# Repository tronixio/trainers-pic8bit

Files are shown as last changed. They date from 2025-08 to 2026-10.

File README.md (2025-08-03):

# PIC 8-Bit Trainers Boards.

## Schematics.

- [**Nano** Trainer.](https://github.com/tronixio/trainers-pic8bit/blob/main/Kicad/nano/extras/schematic.pdf)
- [TODO - Micro Trainer.](https://github.com/tronixio/trainers-pic8bit/blob/main/Kicad/micro/extras/schematic.pdf)
- [**Mini** Trainer.](https://github.com/tronixio/trainers-pic8bit/blob/main/Kicad/mini/extras/schematic.pdf)
- [**PIC 8-Bit** Trainer.](https://github.com/tronixio/trainers-pic8bit/blob/main/Kicad/trainer/extras/schematic.pdf)

## Firmwares.

- [PIC 8-Bit NANO Trainer.](https://github.com/tronixio/trainers-pic8bit/tree/main/Firmwares#pic8-bit-nano-trainer)
- [PIC 8-Bit MINI Trainer.](https://github.com/tronixio/trainers-pic8bit/tree/main/Firmwares#pic8-bit-mini-trainer)
- [PIC 8-Bit Trainer.](https://github.com/tronixio/trainers-pic8bit/tree/main/Firmwares#pic8-bit-trainer)

## Hats & Modules.

- [Trainer Hats](https://github.com/tronixio/modules)
- [Trainer Modules (GPIO/UART/I2C/SPI)](https://github.com/tronixio/modules)

## NANO Trainer Top.

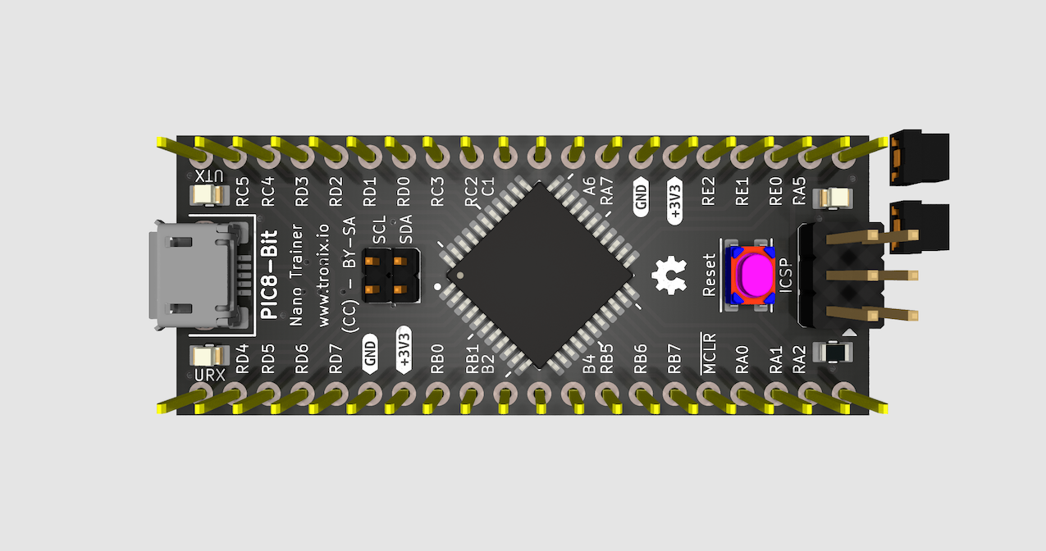
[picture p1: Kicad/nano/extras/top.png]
Nano Trainer Top.


## NANO Trainer Bottom.

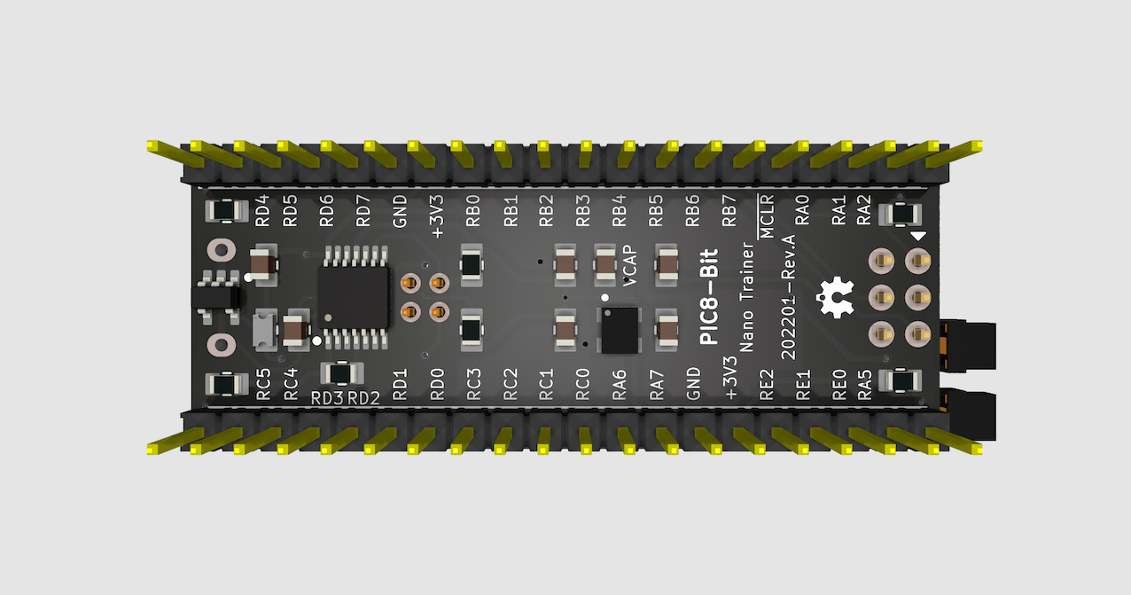
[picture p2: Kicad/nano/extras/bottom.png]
Nano Trainer Bottom.


## MINI Trainer Top.

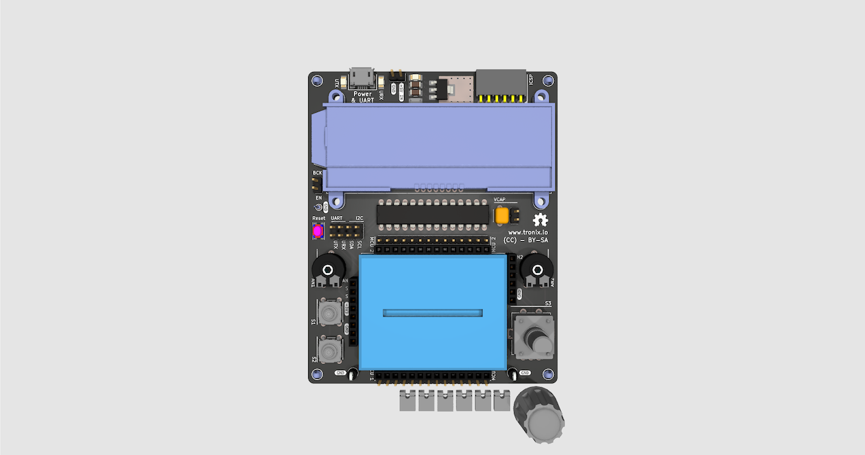
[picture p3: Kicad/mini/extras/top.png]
Mini Trainer Top.


## MINI Trainer Bottom.

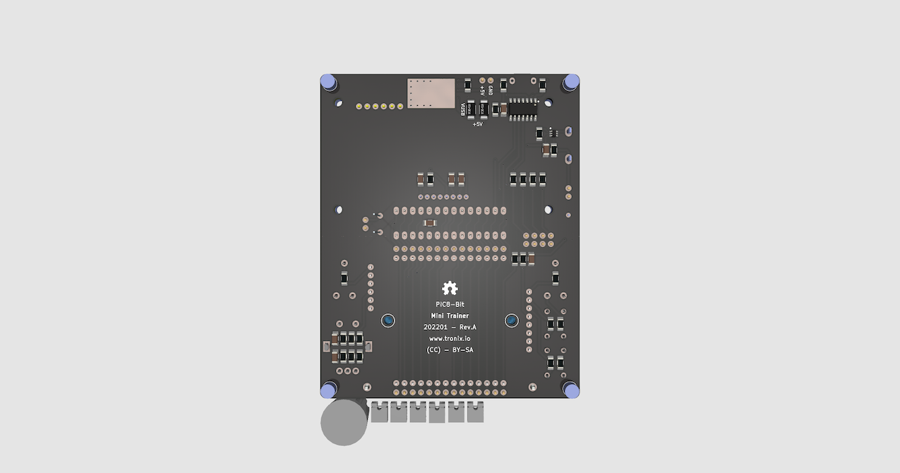
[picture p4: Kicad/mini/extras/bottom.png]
Mini Trainer Bottom.


## PIC 8-Bit Trainer Top.

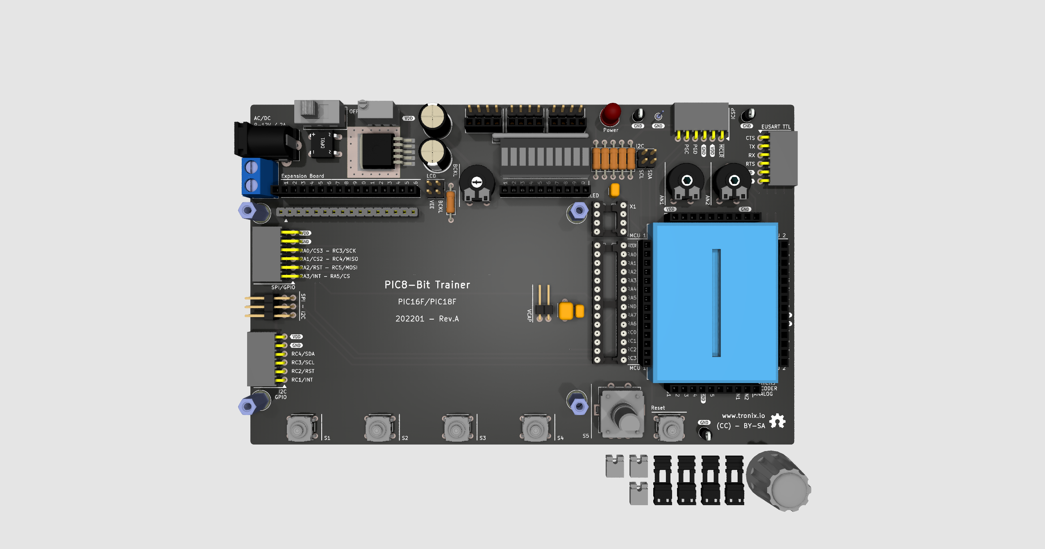
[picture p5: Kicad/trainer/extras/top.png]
PIC 8-Bit Trainer Top.


## PIC 8-Bit Trainer Bottom.

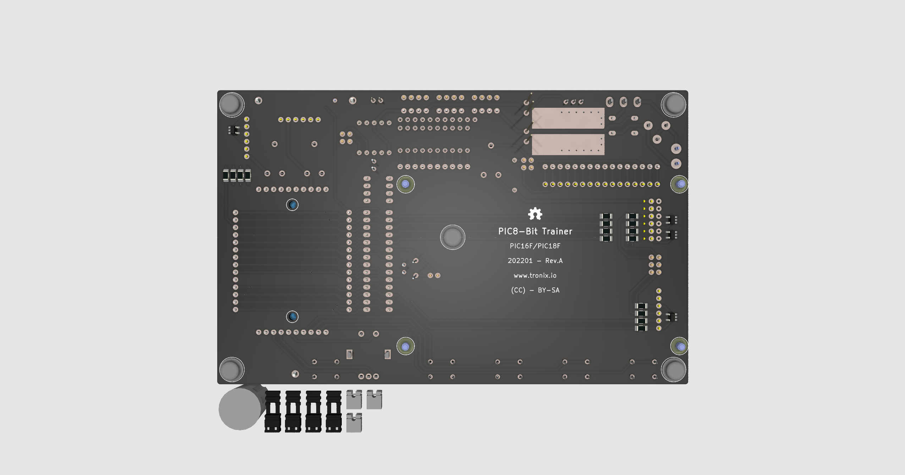
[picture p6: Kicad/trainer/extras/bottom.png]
PIC 8-Bit Trainer Bottom.


## Notes.

- DRAFT : Prototype OK, last check schematic, PCB & code can be modify.
- TODO : Work in progress, prototype was not good, hardware, PCB and code can be rework.

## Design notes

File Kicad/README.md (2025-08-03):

# Trainers Boards PIC 8-Bit.

- [Trainers Boards PIC 8-Bit.](https://github.com/tronixio/trainers-pic8bit)

## Notes.

- TODO : Work in progress, prototype was not good, hardware, PCB and code can be rework.
- DRAFT : Prototype OK, last check schematic, PCB & code can be modify.

## DISCLAIMER.

THIS CODE IS PROVIDED WITHOUT ANY WARRANTY OR GUARANTEES.
USERS MAY USE THIS CODE FOR DEVELOPMENT AND EXAMPLE PURPOSES ONLY.
AUTHORS ARE NOT RESPONSIBLE FOR ANY ERRORS, OMISSIONS, OR DAMAGES THAT COULD
RESULT FROM USING THIS FIRMWARE IN WHOLE OR IN PART.

---

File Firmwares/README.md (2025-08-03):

# FIRMWARES - PIC 8-Bit Trainers Boards.

## PIC8-Bit Nano Trainer.

## PIC8-Bit Mini Trainer.

- [TODO - PIC16f1778 PICAS Eusart](./pic16f17xx/pic16f1778-mini-picas-eusart.s)
- [TODO - PIC16f1778 PICAS LCD](./pic16f17xx/pic16f1778-mini-picas-lcd.s)
- [TODO - PIC16f1778 XC8 EUSART](./pic16f17xx/pic16f1778-mini-xc8-eusart.c)
- [TODO - PIC16f1778 XC8 LCD](./pic16f17xx/pic16f1778-mini-xc8-lcd.c)

## PIC8-Bit Trainer.

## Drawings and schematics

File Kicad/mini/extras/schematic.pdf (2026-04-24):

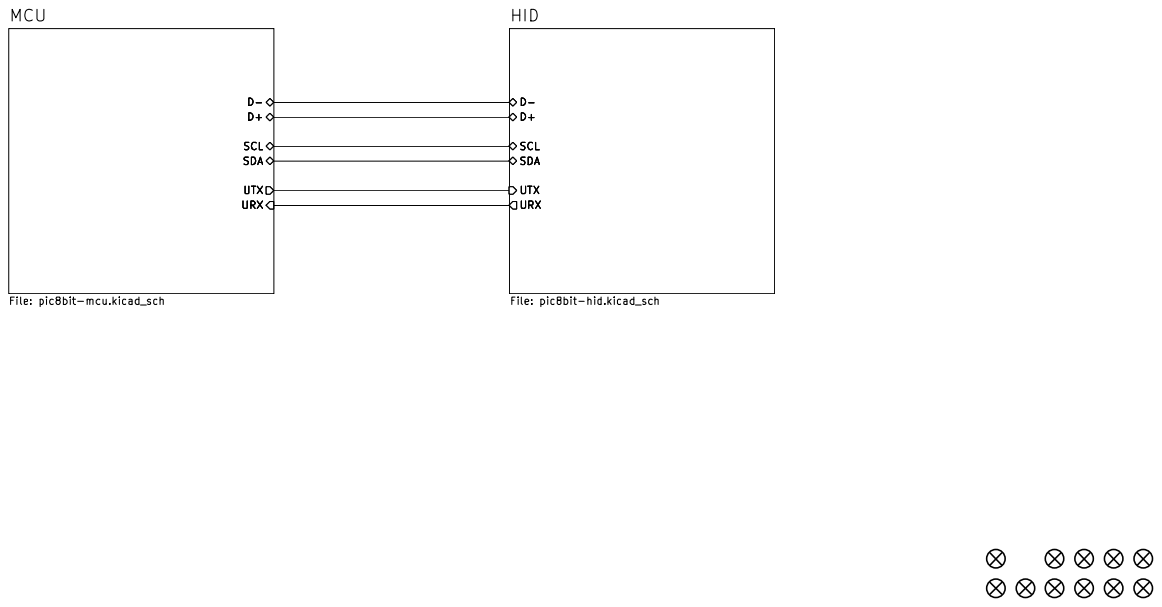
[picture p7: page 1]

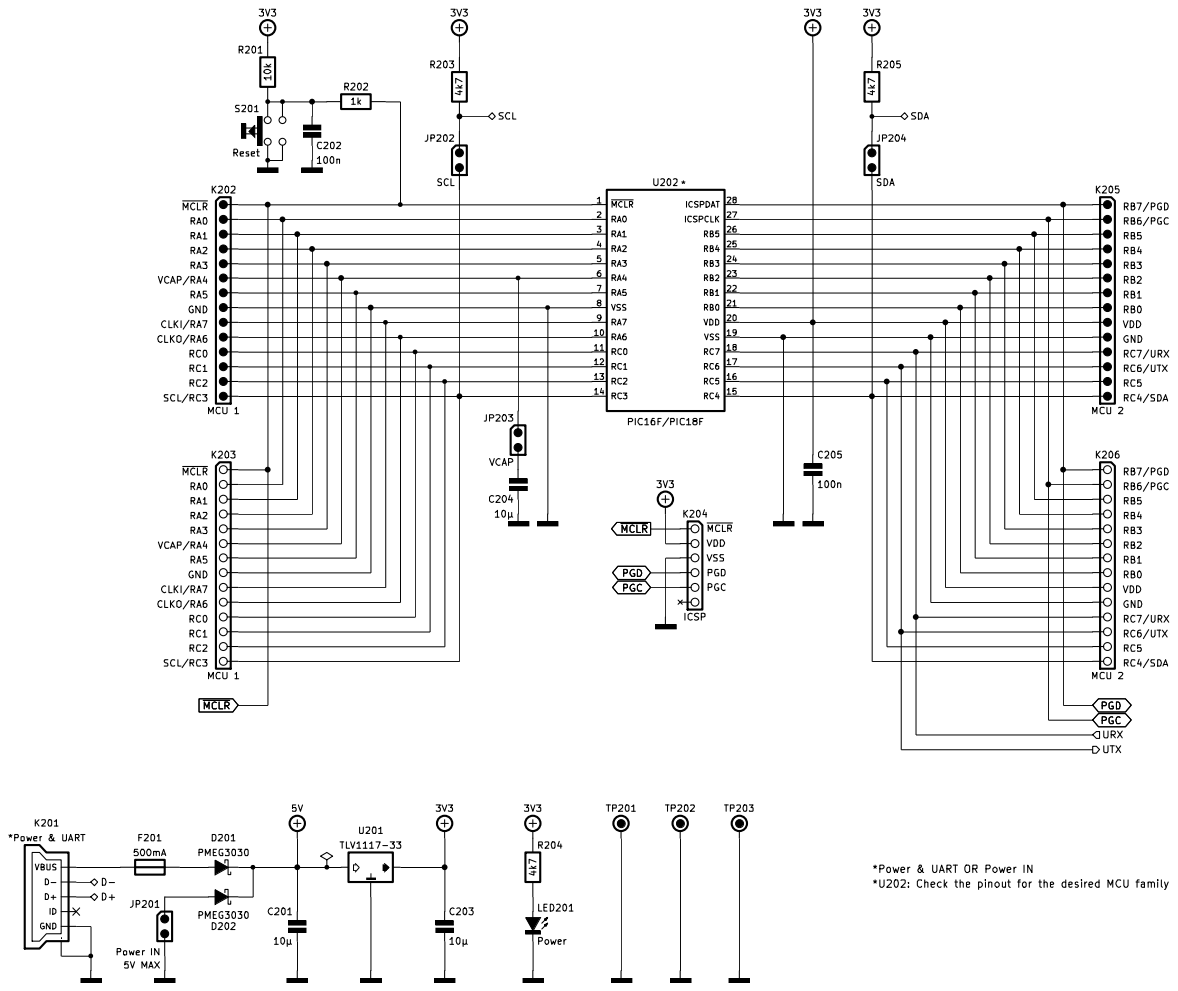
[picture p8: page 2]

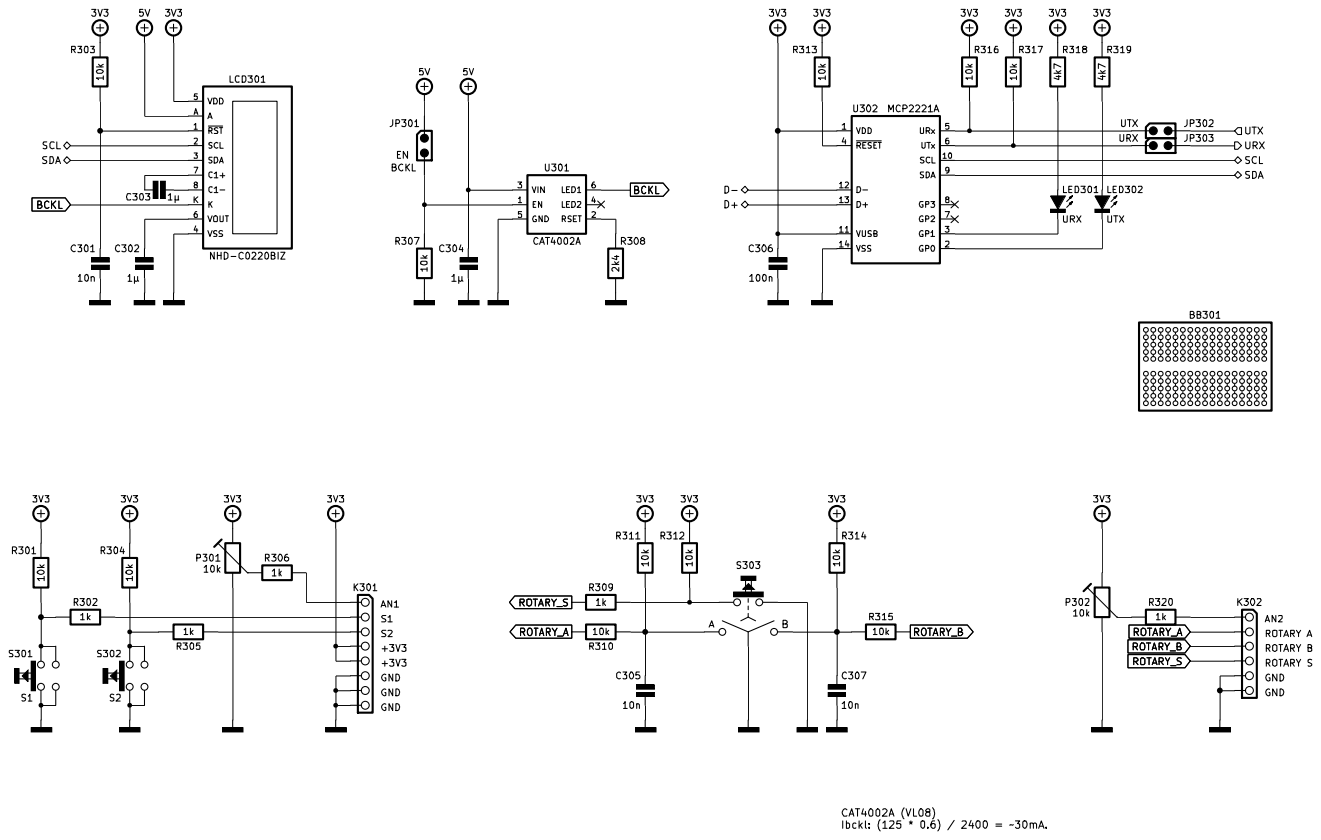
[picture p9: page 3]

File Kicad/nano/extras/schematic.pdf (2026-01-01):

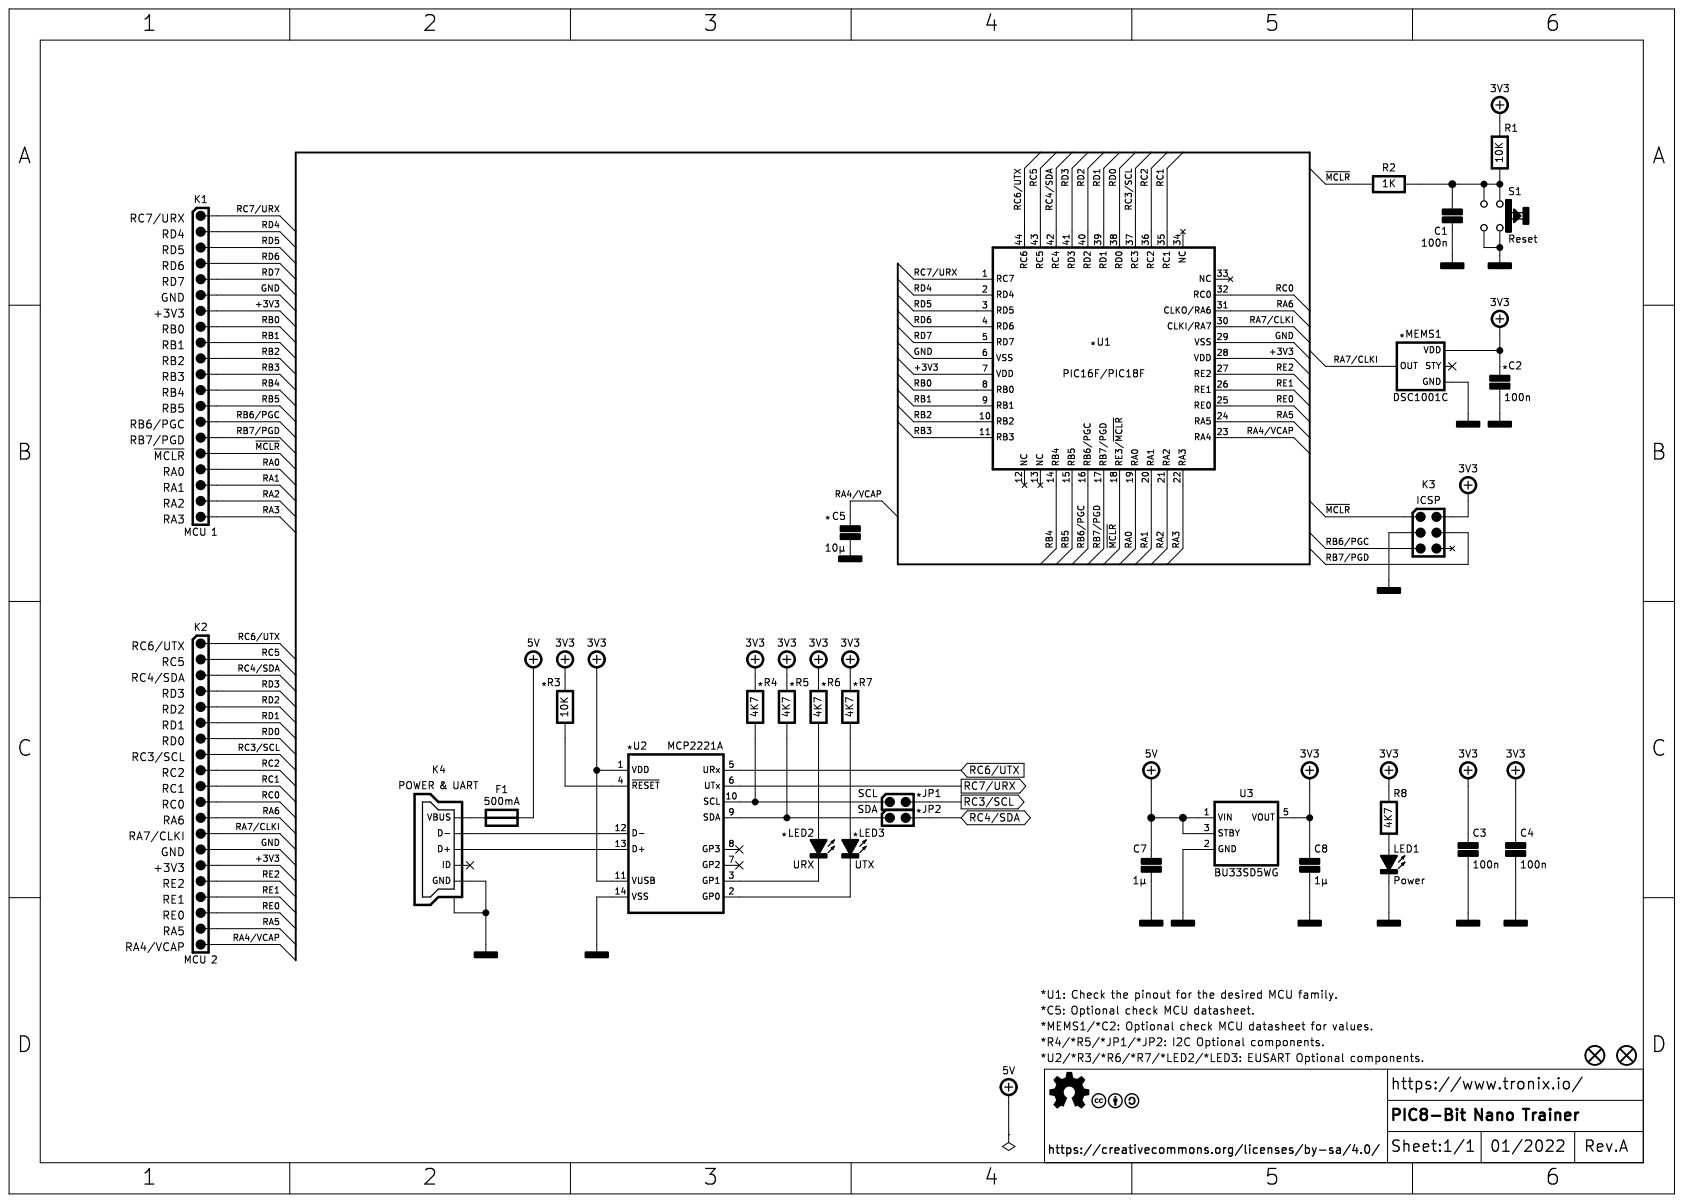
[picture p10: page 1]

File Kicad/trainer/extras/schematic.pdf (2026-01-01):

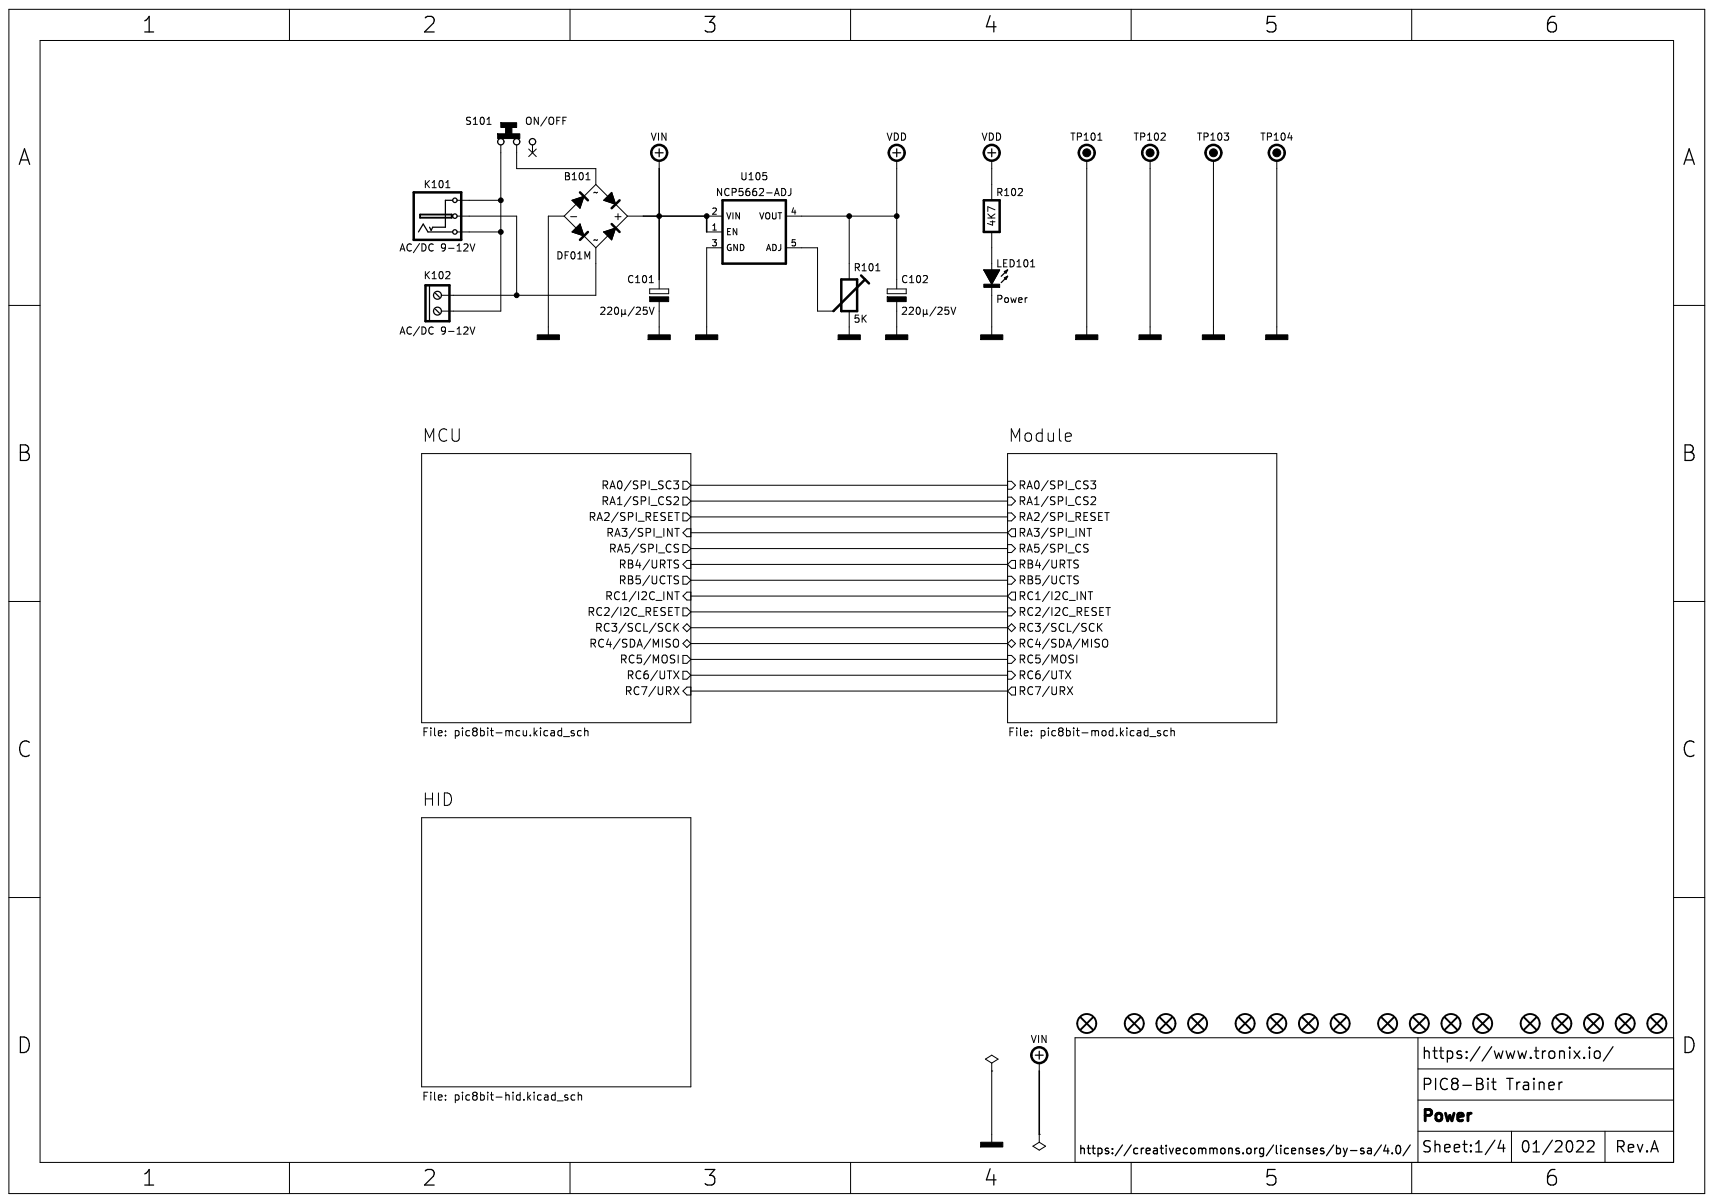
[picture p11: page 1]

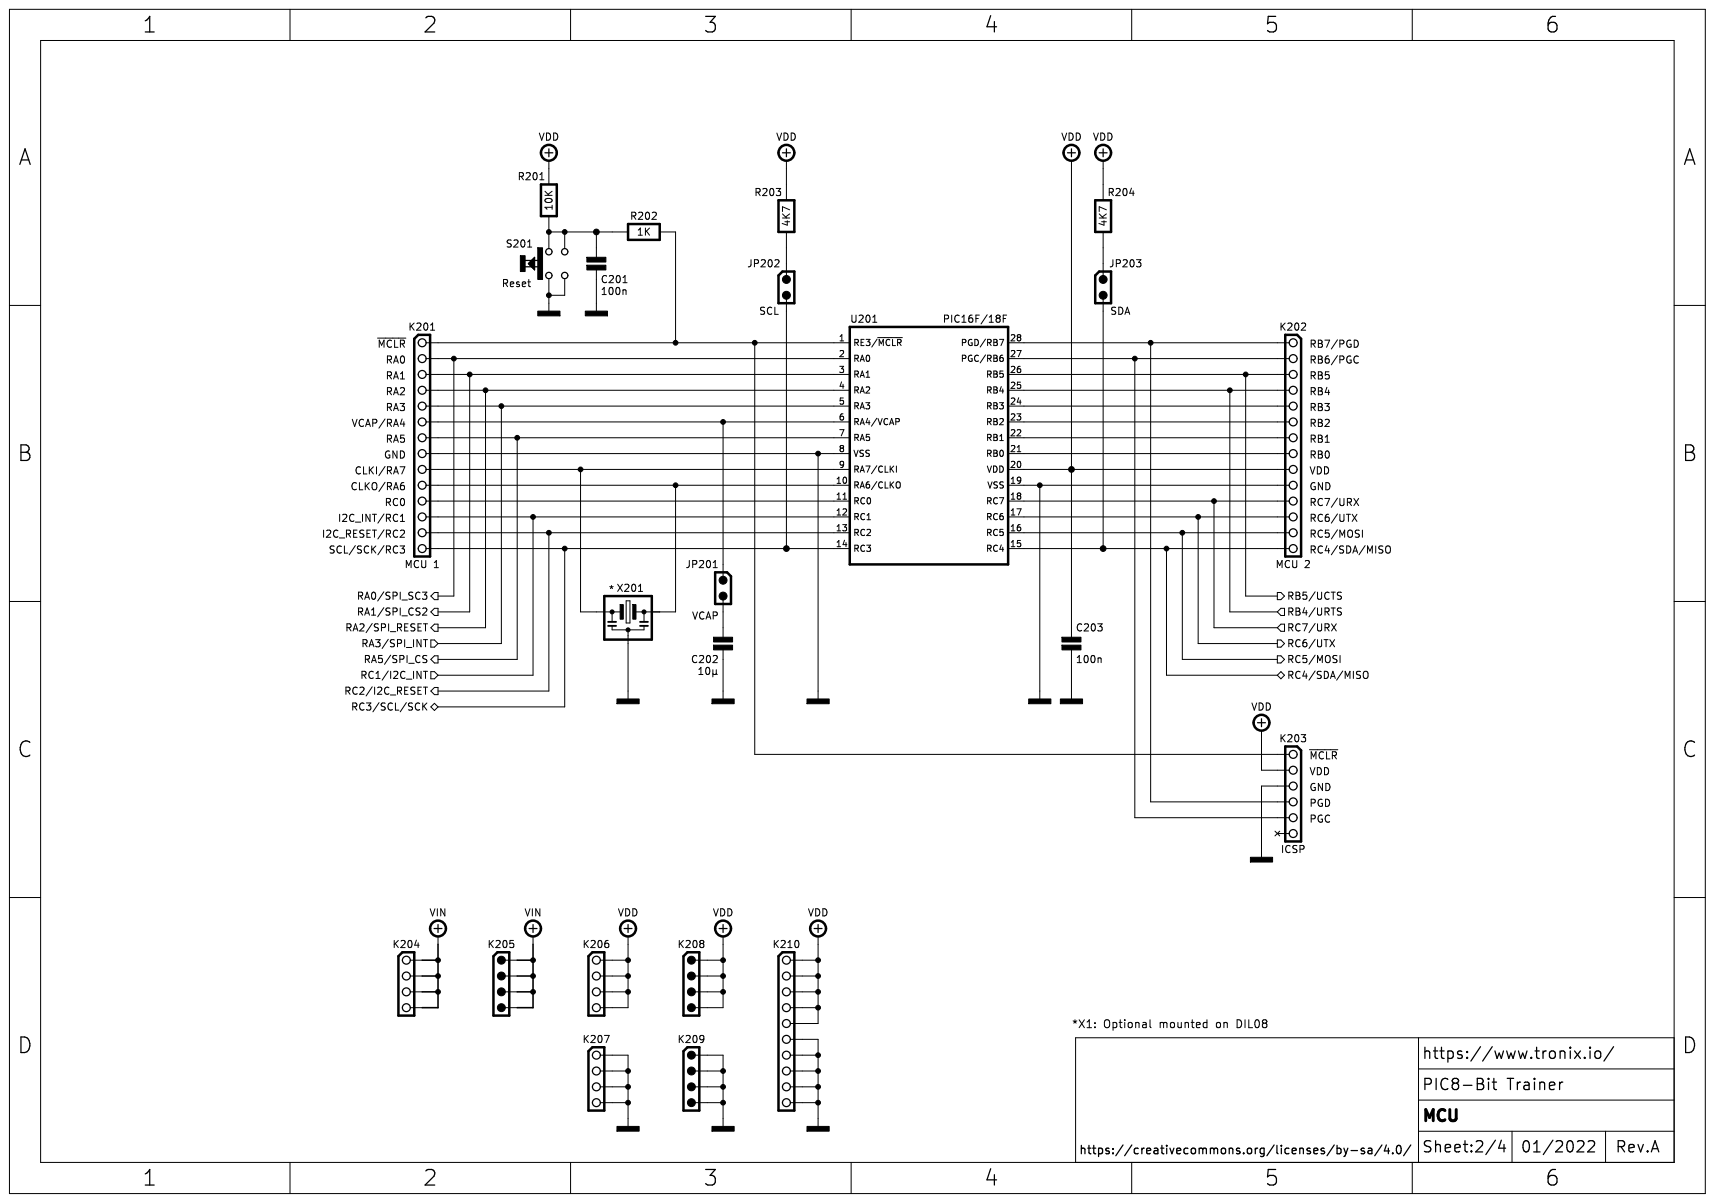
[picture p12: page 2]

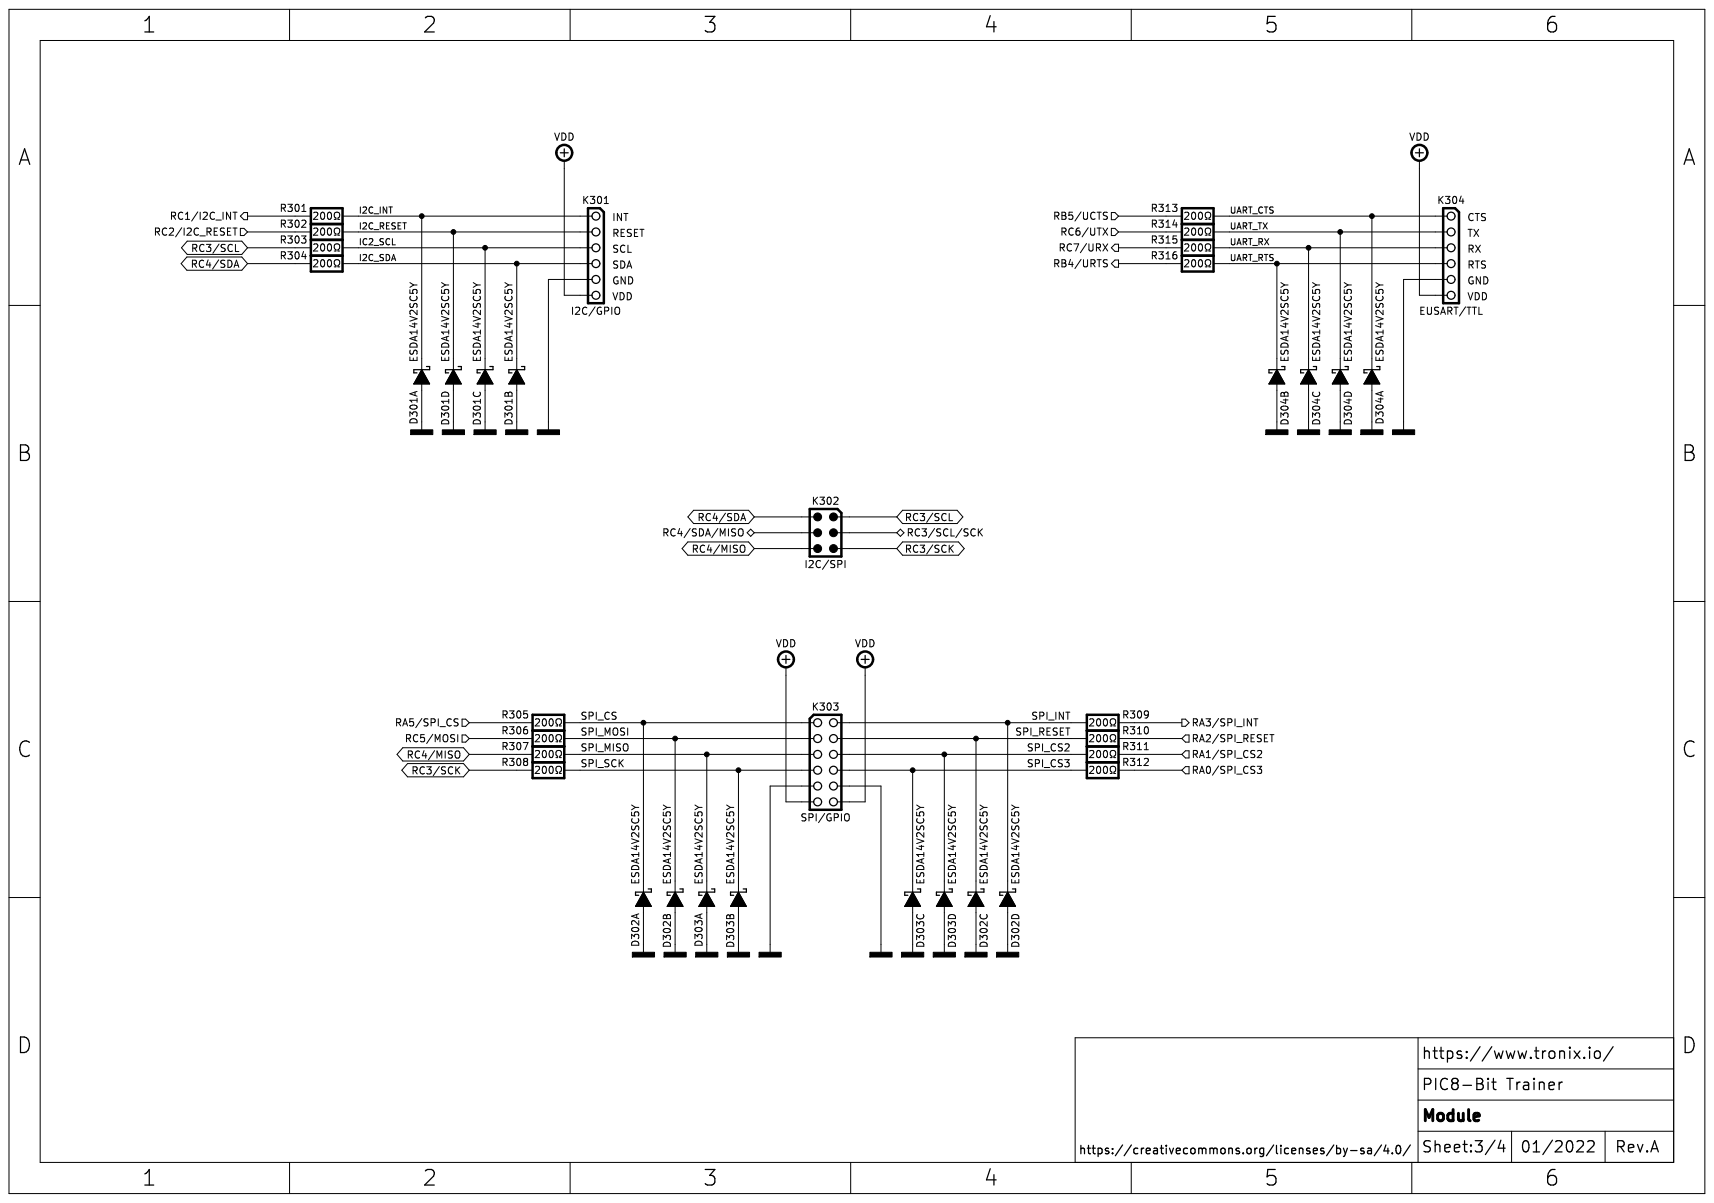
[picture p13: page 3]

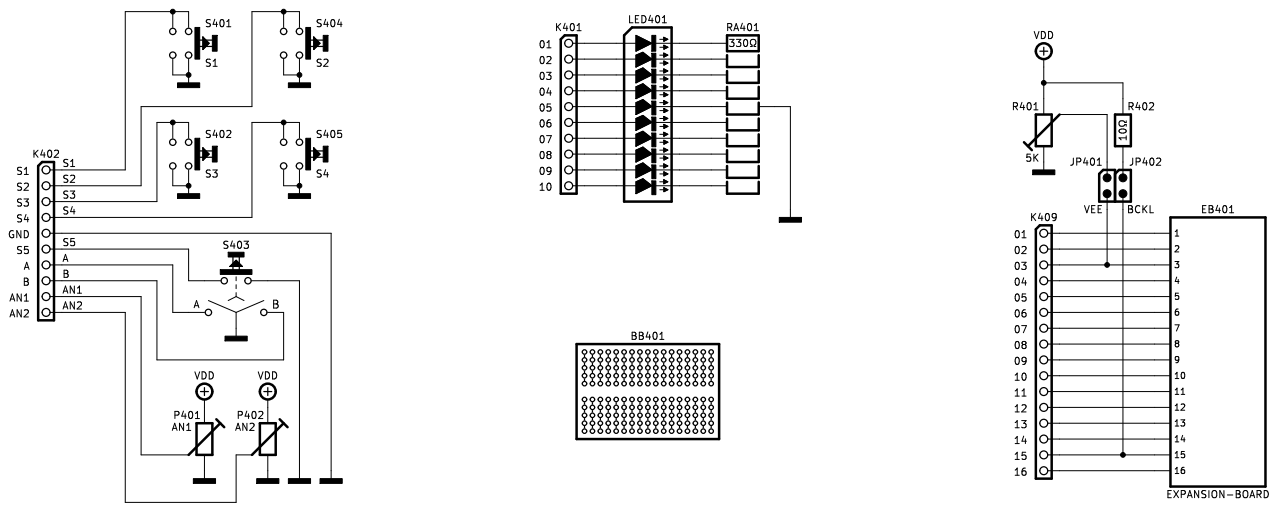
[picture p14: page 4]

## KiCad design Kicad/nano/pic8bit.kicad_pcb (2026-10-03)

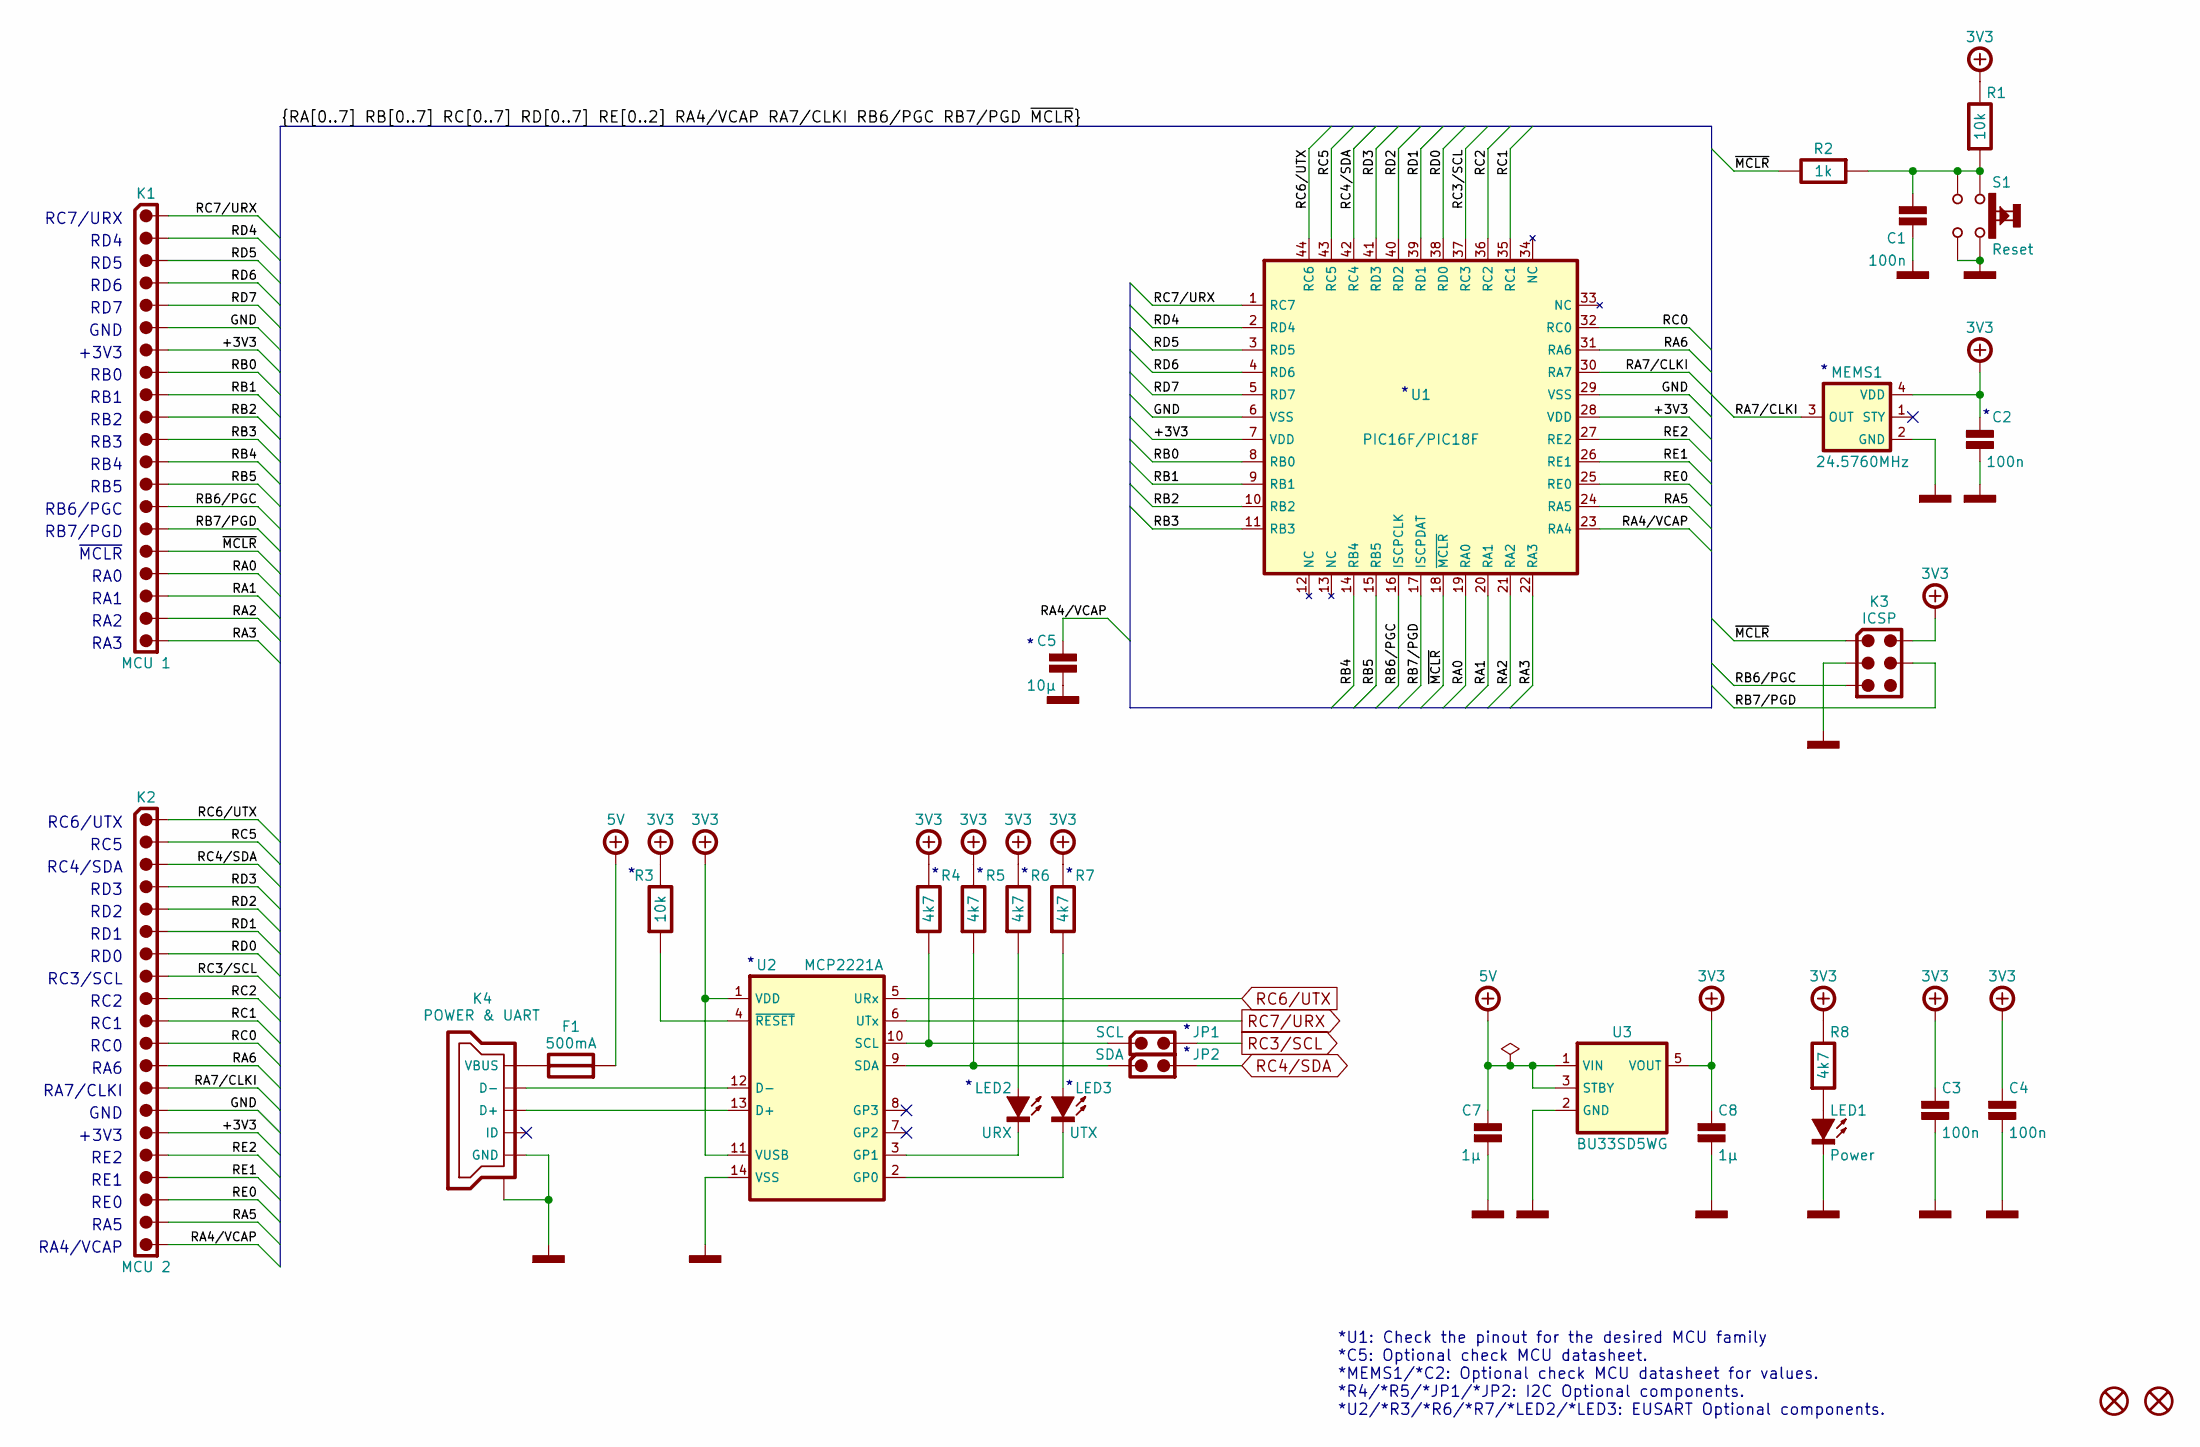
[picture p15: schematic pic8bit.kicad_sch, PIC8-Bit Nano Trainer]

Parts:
C1, C2, C3, C4: 100n; CAPACITOR-SMD-0805; Voltage 50V; Tolerance 5%; Mouser 80-C0805C104J5
C5: 10µ; CAPACITOR-SMD-0805; Voltage 25V; Tolerance 10%; Mouser 81-GRM21BZ71E106
C7, C8: 1µ; CAPACITOR-SMD-0805; Voltage 50V; Tolerance 10%; Mouser 187-CL21B105KBFNNNE
F1: 500mA; FUSE-SMD-0805; Mouser 652-MF-PSMF050X-2
H1, H2: HARWIN-JUMPER-0200-03MM-BLACK; HARWIN-M22-190-19X; Mouser 855-M22-19000
JP1: SCL; HARWIN-M22-25102xx; Mouser 855-M22-25102
JP2: SDA; HARWIN-M22-25102xx; Mouser 855-M22-25102
K1: MCU 1; SAMTEC-TSW-120-22-T-S; Mouser 200-TSW12022TS
K2: MCU 2; SAMTEC-TSW-120-22-T-S; Mouser 200-TSW12022TS
K3: ICSP; HARWIN-M20-998034x; Mouser 855-M20-998034
K4: POWER & UART; USB-TYPE-B-MICRO-TH; Mouser 649-10118193-0001LF
LED1: Power; LED-SMD-0805; Mouser 604-APT2012LVBCD
LED2: URX; LED-SMD-0805; Mouser 604-APT2012LVBCD
LED3: UTX; LED-SMD-0805; Mouser 604-APT2012LVBCD
MEMS1: 24.5760MHz; CDFN-3225; Mouser 998-1001CI2-024.5760
R1, R3: 10k; RESISTOR-SMD-0805; Tolerance 5%; Mouser 660-RK73B2ATTDD103J
R2: 1k; RESISTOR-SMD-0805; Tolerance 5%; Mouser 660-RK73B2ATTDD102J
R4, R5, R6, R7, R8: 4k7; RESISTOR-SMD-0805; Tolerance 5%; Mouser 660-RK73B2ATTDD472J
S1: Reset; ALPS-SKRPAC; Mouser 688-SKRPACE010
U1: PIC16F/PIC18F; TQFP-44; Mouser 579-PIC16F1779-I/PT
U2: MCP2221A; TSSOP-14; Mouser 579-MCP2221A-I/ST
U3: BU33SD5WG; SOT-23-5; Mouser 755-BU33SD5WG-TR

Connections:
+3V3: C2.1, C3.1, C4.1, C8.1, K1.7, K2.15, K3.2 (VCC), MEMS1.4 (VDD), R1.1, R3.1, R4.1, R5.1, R6.1, R7.1, R8.1, U1.7 (VDD), U1.28 (VDD), U2.1 (VDD), U2.11 (VUSB), U3.5 (VOUT)
/RA0: K1.17, U1.19 (RA0)
/RA1: K1.18, U1.20 (RA1)
/RA2: K1.19, U1.21 (RA2)
/RA3: K1.20, U1.22 (RA3)
/RA4/VCAP: C5.1, K2.20, U1.23 (RA4)
/RA5: K2.19, U1.24 (RA5)
/RA6: K2.12, U1.31 (RA6)
/RA7/CLKI: K2.13, MEMS1.3 (OUT), U1.30 (RA7)
/RB0: K1.8, U1.8 (RB0)
/RB1: K1.9, U1.9 (RB1)
/RB2: K1.10, U1.10 (RB2)
/RB3: K1.11, U1.11 (RB3)
/RB4: K1.12, U1.14 (RB4)
/RB5: K1.13, U1.15 (RB5)
/RB6/PGC: K1.14, K3.5 (ICSPCLK), U1.16 (ISCPCLK)
/RB7/PGD: K1.15, K3.4 (ICSPDAT), U1.17 (ISCPDAT)
/RC0: K2.11, U1.32 (RC0)
/RC1: K2.10, U1.35 (RC1)
/RC2: K2.9, U1.36 (RC2)
/RC5: K2.2, U1.43 (RC5)
/RD0: K2.7, U1.38 (RD0)
/RD1: K2.6, U1.39 (RD1)
/RD2: K2.5, U1.40 (RD2)
/RD3: K2.4, U1.41 (RD3)
/RD4: K1.2, U1.2 (RD4)
/RD5: K1.3, U1.3 (RD5)
/RD6: K1.4, U1.4 (RD6)
/RD7: K1.5, U1.5 (RD7)
/RE0: K2.18, U1.25 (RE0)
/RE1: K2.17, U1.26 (RE1)
/RE2: K2.16, U1.27 (RE2)
/~MCLR: K1.16, K3.1 (~MCLR), R2.1, U1.18 (~MCLR)
GND: C1.2, C2.2, C3.2, C4.2, C5.2, C7.2, C8.2, K1.6, K2.14, K3.3 (GND), K4.5 (GND), K4.SH (SHIELD), LED1.1 (C), MEMS1.2 (GND), S1.3, S1.4, U1.6 (VSS), U1.29 (VSS), U2.14 (VSS), U3.2 (GND)
unnamed: C1.1, R1.2, R2.2, S1.1, S1.2
unnamed: K4.3 (D+), U2.13 (D+)
unnamed: K4.2 (D-), U2.12 (D-)
unnamed: F1.1, K4.1 (VBUS)
unnamed: LED1.2 (A), R8.2
unnamed: LED2.2 (A), R6.2
unnamed: LED2.1 (C), U2.3 (GP1)
unnamed: LED3.2 (A), R7.2
unnamed: LED3.1 (C), U2.2 (GP0)
unnamed: JP1.1, R4.2, U2.10 (SCL)
unnamed: JP2.1, R5.2, U2.9 (SDA)
unnamed: R3.2, U2.4 (~RESET)
POWER-+5V: C7.1, F1.2, U3.1 (VIN), U3.3 (STBY)
RC3/SCL: JP1.2, K2.8, U1.37 (RC3)
RC4/SDA: JP2.2, K2.3, U1.42 (RC4)
RC6/UTX: K2.1, U1.44 (RC6), U2.5 (URx)
RC7/URX: K1.1, U1.1 (RC7), U2.6 (UTx)

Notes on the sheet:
RD7
RA7/CLKI
RB0
RD5
RC6/UTX
GND
RB4
RA4/VCAP
RB1
RE0
RC3/SCL
~{MCLR}
RB2
+3V3
RE1
RB5
RA6
RD1
RD3
RD6
RB3
RA3
*U1: Check the pinout for the desired MCU family *C5: Optional check MCU datasheet. *MEMS1/*C2: Optional check MCU datasheet for values. *R4/*R5/*JP1/*JP2: I2C Optional components. *U2/*R3/*R6/*R7/*LED2/*LED3: EUSART Optional components.
RE2
RA1
RB7/PGD
RA2
RC5
RC0
RC4/SDA
RA0
RA5
RB6/PGC
RD2
RD0
RC2
RC7/URX
RC1
RD4

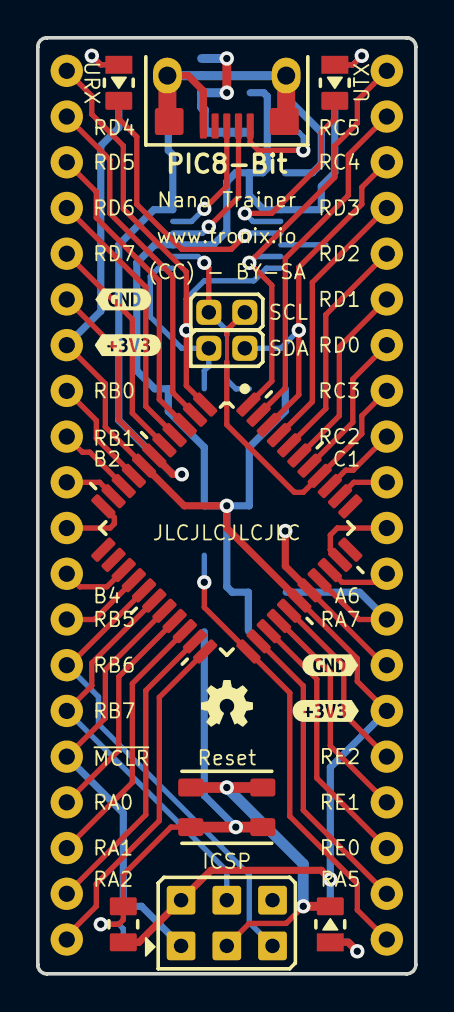
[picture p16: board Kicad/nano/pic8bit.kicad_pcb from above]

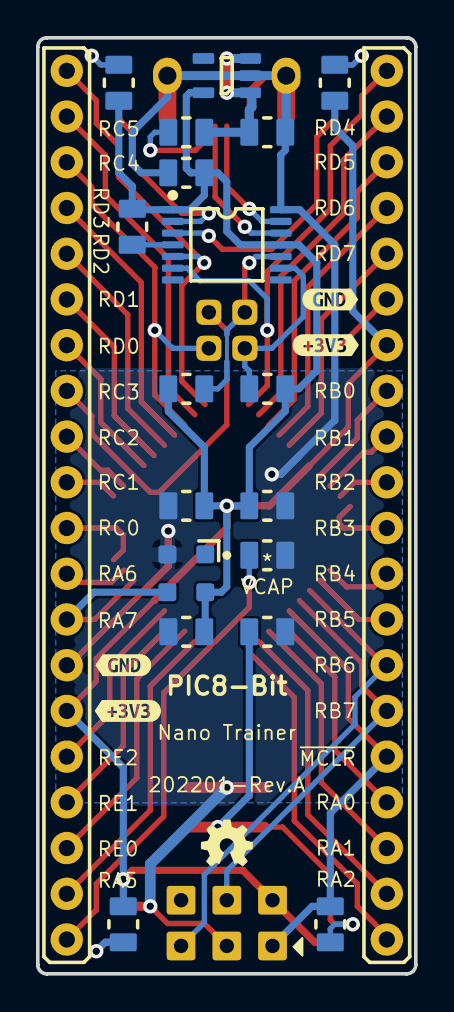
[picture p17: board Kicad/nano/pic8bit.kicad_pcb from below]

Board: 2 copper layers, 21.0 x 52.0 mm, 42 parts (25 on the bottom side), 51 nets.

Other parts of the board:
GB: LOGO; OSHW-3MM
GT: LOGO; OSHW-3MM
kibuzzard-65F5BE0B: G***; kibuzzard-65F5BE0B
kibuzzard-65F5BE2C: G***; kibuzzard-65F5BE2C
kibuzzard-65F5BE3D: G***; kibuzzard-65F5BE3D
kibuzzard-65F5BE5D: G***; kibuzzard-65F5BE5D
kibuzzard-65F5BE6D: G***; kibuzzard-65F5BE6D
kibuzzard-65F5BE7D: G***; kibuzzard-65F5BE7D
kibuzzard-65F5BE8C: G***; kibuzzard-65F5BE8C
kibuzzard-65F5BE49: G***; kibuzzard-65F5BE49

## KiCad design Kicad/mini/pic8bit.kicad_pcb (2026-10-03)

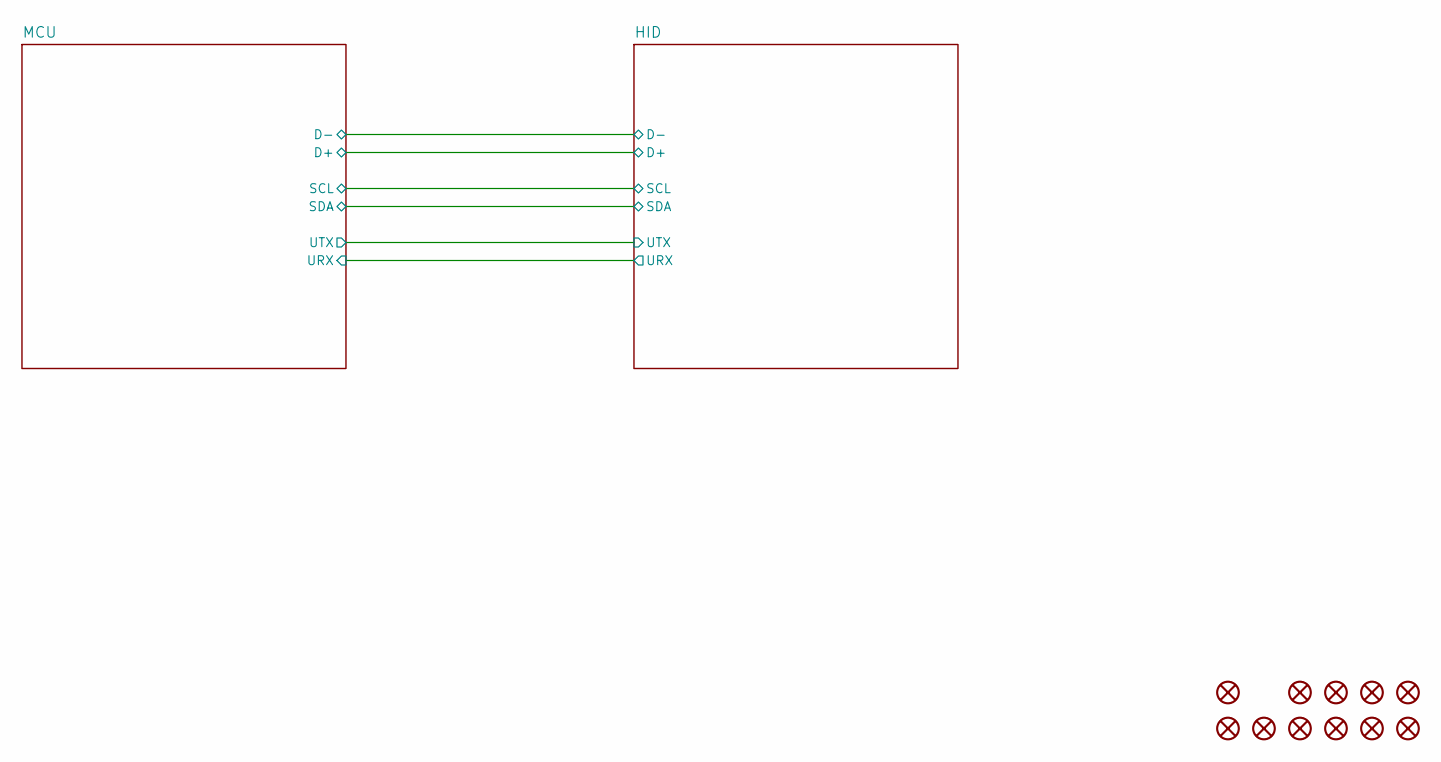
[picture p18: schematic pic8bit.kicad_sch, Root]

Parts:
H101, H102, H103, H104: KEYSTONE-9055; Mouser 534-9055
JP101, JP102, JP103, JP104, JP105, JP106: HARWIN-JUMPER-0254-06MM-BLACK; HARWIN-M20-7580-7583; Mouser 855-M7582
K101: PE-450-4X6X-BLACK; PE-450-4X6X; Mouser 450-476

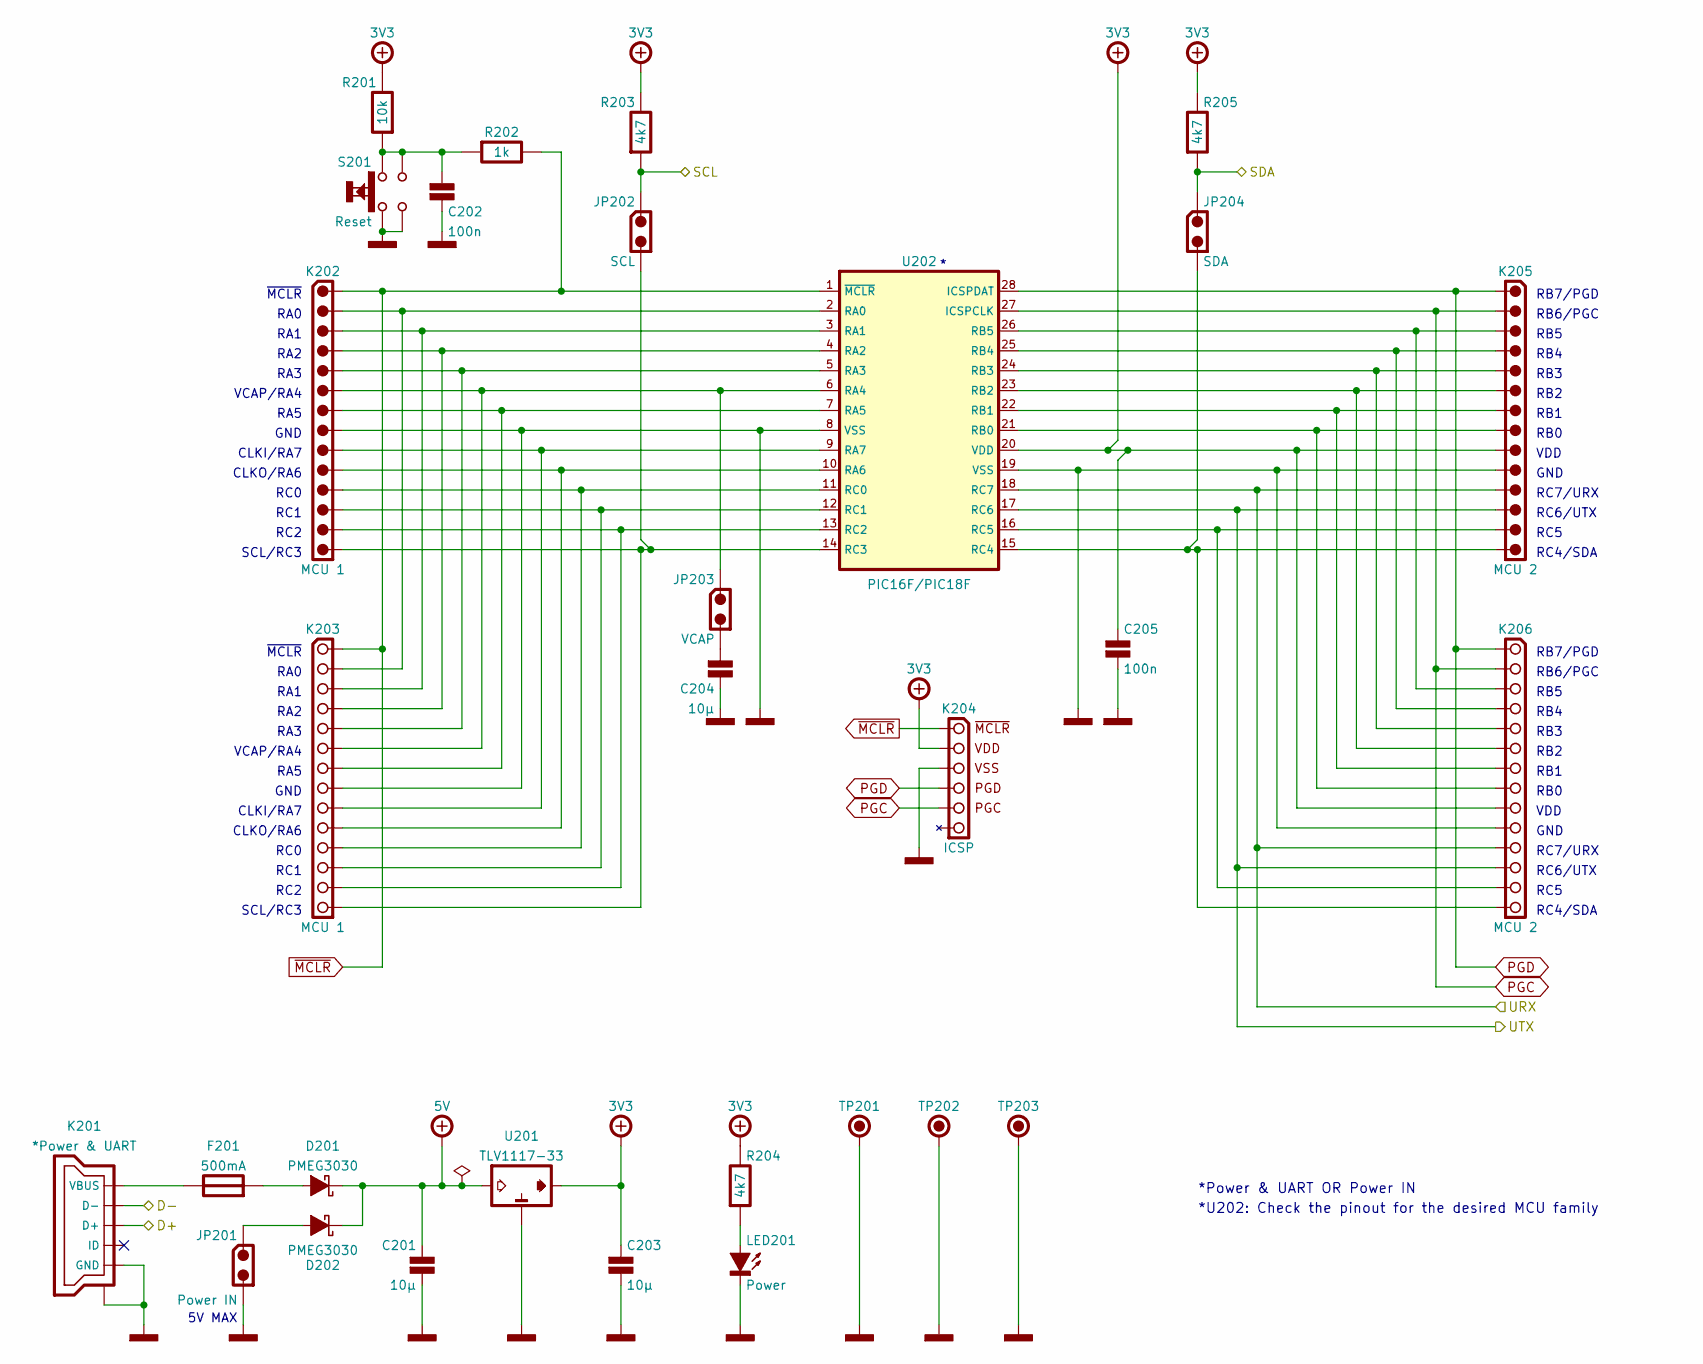
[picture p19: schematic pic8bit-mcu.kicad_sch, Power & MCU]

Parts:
C201, C203, C204: 10µ; CAPACITOR-SMD-1206; Tolerance 5%; Voltage 25V; Mouser 80-C1206C106J3R
C202, C205: 100n; CAPACITOR-SMD-1206; Voltage 50V; Tolerance 5%; Mouser 80-C1206C104J5R
D201, D202: PMEG3030; SOD-128; Part Marking A5; Mouser 771-PMEG3030EP115
F201: 500mA; FUSE-SMD-1206; Mouser 652-MF-NSMF050-2
JP201: Power IN; HARWIN-M20-999024x; Mouser 855-M20-999024
JP202: SCL; HARWIN-M20-999024x; Mouser 855-M20-999024
JP203: VCAP; HARWIN-M20-999024x; Mouser 855-M20-999024
JP204: SDA; HARWIN-M20-999024x; Mouser 855-M20-999024
K201: *Power & UART; USB-TYPE-B-MICRO-TH; Mouser 649-10118193-0001LF
K202: MCU 1; HARWIN-M20-999144x; Mouser 855-M20-999144
K203: MCU 1; HARWIN-M20-782144x; Mouser 855-M20-782144
K204: ICSP; SAMTEC-SSW-106-02-T-S-RA; Mouser 200-SSW10602TSRA
K205: MCU 2; HARWIN-M20-999144x; Mouser 855-M20-999144
K206: MCU 2; HARWIN-M20-782144x; Mouser 855-M20-782144
LED201: Power; LED-SMD-1206; Mouser 604-APT3216LVBCD
R201: 10k; RESISTOR-SMD-1206; Tolerance 5%; Mouser 660-RK73B2BTTDD103J
R202: 1k; RESISTOR-SMD-1206; Tolerance 5%; Mouser 660-RK73B2BTTDD102J
R203, R204, R205: 4k7; RESISTOR-SMD-1206; Tolerance 5%; Mouser 660-RK73B2BTTDD472J
S201: Reset; ALPS-SKRPAC; Mouser 688-SKRPACE010
TP201, TP202: KEYSTONE-5006; Mouser 534-5006
TP203: KEYSTONE-2000-3; Mouser 534-2000-3
U201: TLV1117-33; SOT-223-3-TABPIN2; Mouser 595-TLV1117-33CDC
U202: PIC16F/PIC18F; DIP-28-W762; Mouser 579-PIC16F1778-I/SP

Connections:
/HID/D+: K201.3 (D+); also elsewhere on the board
/HID/D-: K201.2 (D-); also elsewhere on the board
/HID/SCL: JP202.1, R203.2; also elsewhere on the board
/HID/SDA: JP204.1, R205.2; also elsewhere on the board
/HID/URX: K205.11, K206.11, U202.18 (RC7); also elsewhere on the board
/HID/UTX: K205.12, K206.12, U202.17 (RC6); also elsewhere on the board
unnamed: C202.1, R201.2, R202.2, S201.1, S201.2
unnamed: C204.1, JP203.2
unnamed: D201.2 (A), F201.2
unnamed: D202.2 (A), JP201.1
unnamed: F201.1, K201.1 (VBUS)
unnamed: K202.2, K203.2, U202.2 (RA0)
unnamed: K202.3, K203.3, U202.3 (RA1)
unnamed: K202.4, K203.4, U202.4 (RA2)
unnamed: K202.5, K203.5, U202.5 (RA3)
unnamed: JP203.1, K202.6, K203.6, U202.6 (RA4)
unnamed: K202.7, K203.7, U202.7 (RA5)
unnamed: K202.9, K203.9, U202.9 (RA7)
unnamed: K202.10, K203.10, U202.10 (RA6)
unnamed: K202.11, K203.11, U202.11 (RC0)
unnamed: K202.12, K203.12, U202.12 (RC1)
unnamed: K202.13, K203.13, U202.13 (RC2)
unnamed: JP202.2, K202.14, K203.14, U202.14 (RC3)
unnamed: K205.3, K206.3, U202.26 (RB5)
unnamed: K205.4, K206.4, U202.25 (RB4)
unnamed: K205.5, K206.5, U202.24 (RB3)
unnamed: K205.6, K206.6, U202.23 (RB2)
unnamed: K205.7, K206.7, U202.22 (RB1)
unnamed: K205.8, K206.8, U202.21 (RB0)
unnamed: K205.13, K206.13, U202.16 (RC5)
unnamed: JP204.2, K205.14, K206.14, U202.15 (RC4)
unnamed: LED201.2 (A), R204.2
PGC: K204.2 (PGC), K205.2, K206.2, U202.27 (ICSPCLK)
PGD: K204.3 (PGD), K205.1, K206.1, U202.28 (ICSPDAT)
POWER-+3V3: C203.1, C205.1, K204.5 (VCC), K205.9, K206.9, R201.1, R203.1, R204.1, R205.1, U201.2 (VOUT), U202.20 (VDD); also elsewhere on the board
POWER-+5V: C201.1, D201.1 (C), D202.1 (C), U201.3 (VIN); also elsewhere on the board
POWER-GND: C201.2, C202.2, C203.2, C204.2, C205.2, JP201.2, K201.5 (GND), K201.SH (SHIELD), K202.8, K203.8, K204.4 (GND), K205.10, K206.10, LED201.1 (C), S201.3, S201.4, TP201.1, TP202.1, TP203.1, U201.1 (GND), U202.8 (VSS), U202.19 (VSS); also elsewhere on the board
~MCLR: K202.1, K203.1, K204.6 (~MCLR), R202.1, U202.1 (~MCLR)

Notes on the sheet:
RC6/UTX
*U202: Check the pinout for the desired MCU family
GND
RB3
~{MCLR}
VCAP/RA4
*Power & UART OR Power IN
CLKI/RA7
RC5
RB6/PGC
RA2
VDD
RA3
RC0
RA0
RC1
RB7/PGD
RB5
RB2
RA5
RB1
RA1
CLKO/RA6
SCL/RC3
RB4
RC7/URX
RB0
5V MAX
RC4/SDA
RC2

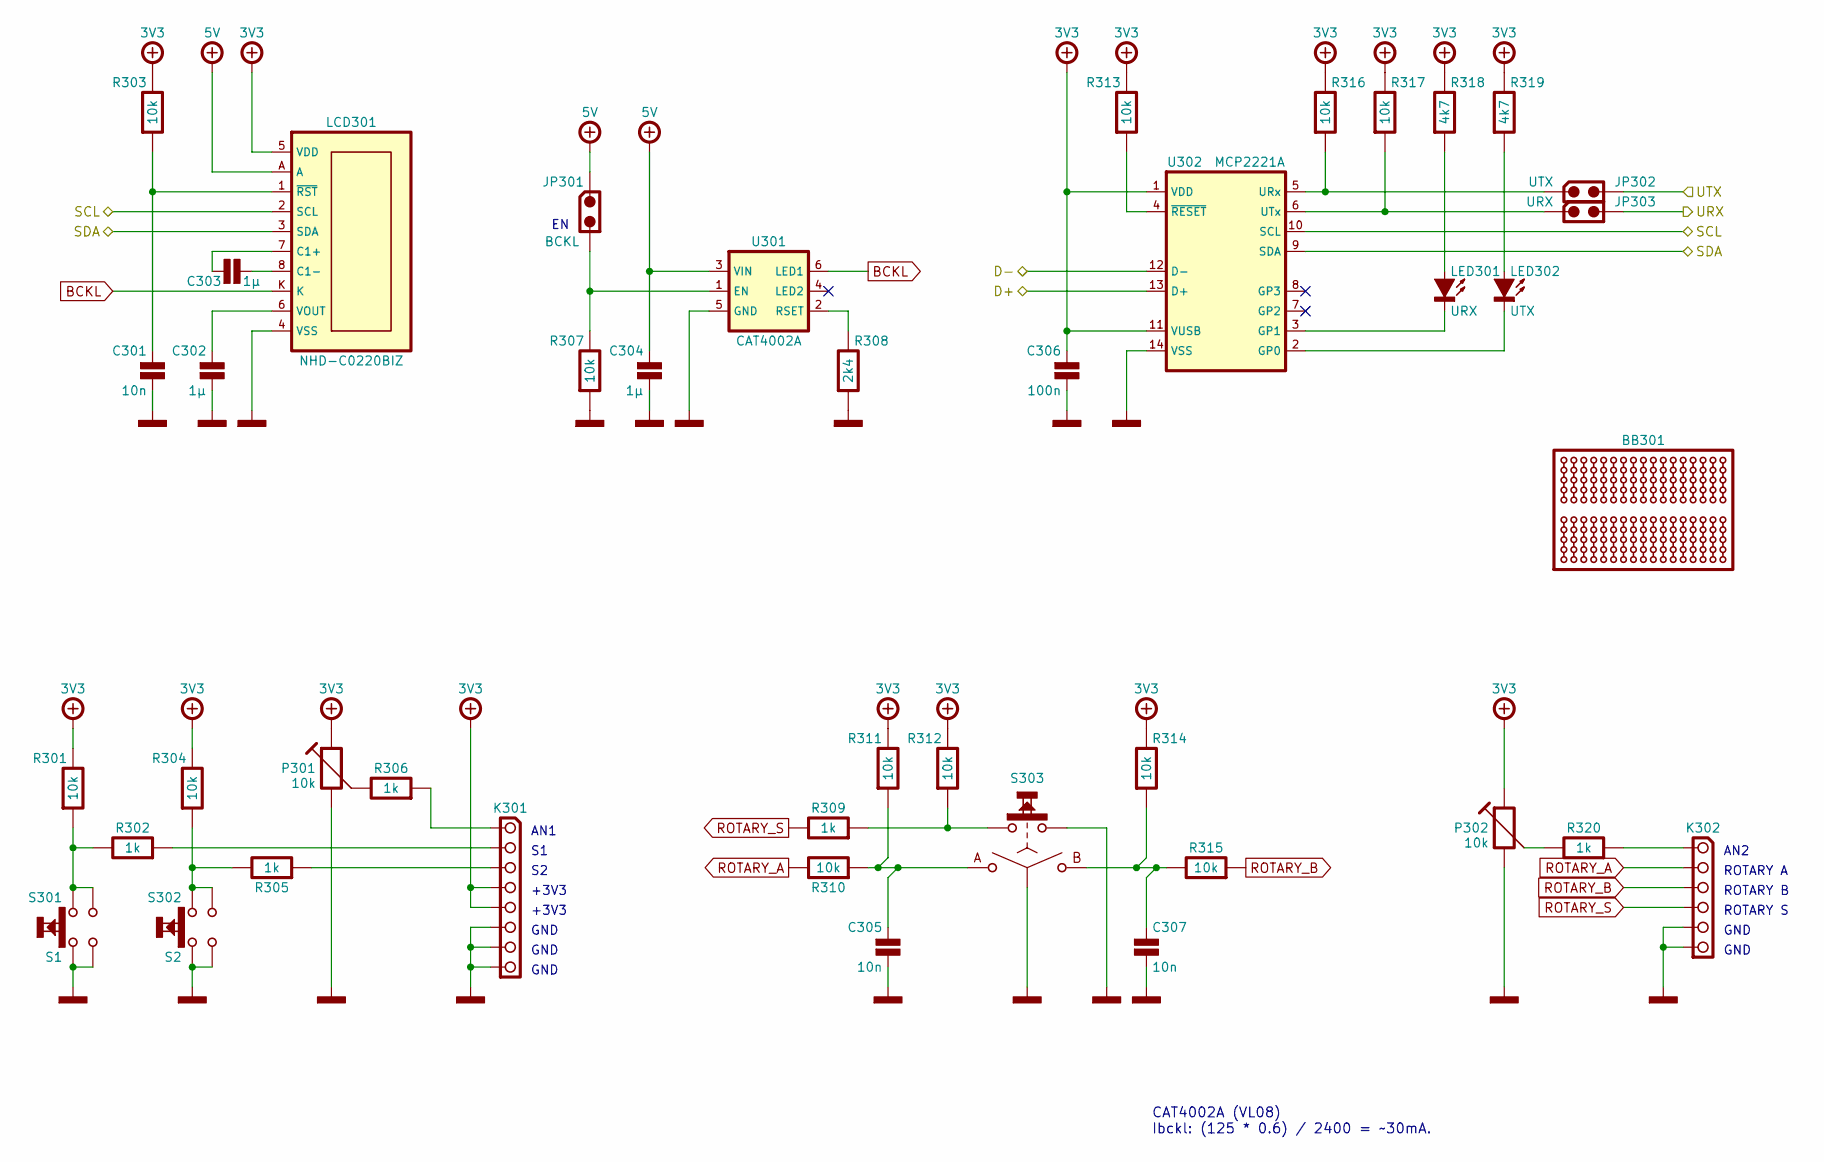
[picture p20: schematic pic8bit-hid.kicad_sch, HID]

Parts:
BB301: BREADBOARD-170; Mouser 854-BB170
C301, C305, C307: 10n; CAPACITOR-SMD-1206; Voltage 100V; Tolerance 5%; Mouser 80-C1206C103J1R
C302, C303, C304: 1µ; CAPACITOR-SMD-1206; Voltage 16V; Tolerance 10%; Mouser 80-C1206C105K4R
C306: 100n; CAPACITOR-SMD-1206; Voltage 50V; Tolerance 5%; Mouser 80-C1206C104J5R
JP301: BCKL; HARWIN-M20-999024x; Mouser 855-M20-999024
JP302: UTX; HARWIN-M20-999024x; Mouser 855-M20-999024
JP303: URX; HARWIN-M20-999024x; Mouser 855-M20-999024
K301: HARWIN-254-F-1X08-VERTICAL; HARWIN-M20-782084x; Mouser 855-M20-782084
K302: HARWIN-254-F-1X06-VERTICAL; HARWIN-M20-782064x; Mouser 855-M20-782064
LCD301: NHD-C0220BIZ; Mouser 763-C0220BIZ-FSW-FBW
LED301: URX; LED-SMD-1206; Mouser 604-APT3216LVBCD
LED302: UTX; LED-SMD-1206; Mouser 604-APT3216LVBCD
P301, P302: 10k; PIHER-PT10MV; Tolerance 20%; Mouser 531-PT10MV-10K
R301, R303, R304, R307, R310, R311, R312, R313, R314, R315, R316, R317: 10k; RESISTOR-SMD-1206; Tolerance 5%; Mouser 660-RK73B2BTTDD103J
R302, R305, R306, R309, R320: 1k; RESISTOR-SMD-1206; Tolerance 5%; Mouser 660-RK73B2BTTDD102J
R308: 2k4; RESISTOR-SMD-1206; Tolerance 5%; Mouser 660-RK73B2BTTDD242J
R318, R319: 4k7; RESISTOR-SMD-1206; Tolerance 5%; Mouser 660-RK73B2BTTDD472J
S301: S1; CK-KSA-TH; Mouser 611-KSA0M911LFT
S302: S2; CK-KSA-TH; Mouser 611-KSA0M911LFT
S303: BOURNS-PEC12R-24DENTS-SWITCH; BOURNS-PEC12R-SWITCH; Mouser 652-PEC12R-4215F-S24
U301: CAT4002A; SC-70-6; Mouser 863-CAT4002ASD-GT3
U302: MCP2221A; SOIC-14; Mouser 579-MCP2221A-I/SL

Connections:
/HID/D+: U302.13 (D+); also elsewhere on the board
/HID/D-: U302.12 (D-); also elsewhere on the board
/HID/SCL: LCD301.2 (SCL), U302.10 (SCL); also elsewhere on the board
/HID/SDA: LCD301.3 (SDA), U302.9 (SDA); also elsewhere on the board
/HID/URX: JP303.2; also elsewhere on the board
/HID/UTX: JP302.2; also elsewhere on the board
BCKL: LCD301.K, U301.6 (LED1)
unnamed: K301.1, R306.2
unnamed: K301.2, R302.2
unnamed: K301.3, R305.2
unnamed: K302.1, R320.2
unnamed: C303.1, LCD301.7 (C1+)
unnamed: C303.2, LCD301.8 (C1-)
unnamed: C302.1, LCD301.6 (VOUT)
unnamed: C301.1, LCD301.1 (~RST), R303.2
unnamed: LED301.2 (A), R318.2
unnamed: LED301.1 (C), U302.3 (GP1)
unnamed: LED302.2 (A), R319.2
unnamed: LED302.1 (C), U302.2 (GP0)
unnamed: P301.2, R306.1
unnamed: P302.2, R320.1
unnamed: R301.2, R302.1, S301.3, S301.4
unnamed: R304.2, R305.1, S302.3, S302.4
unnamed: R309.2, R312.2, S303.5
unnamed: C305.1, R310.2, R311.2, S303.1 (A)
unnamed: C307.1, R314.2, R315.1, S303.3 (B)
unnamed: JP301.2, R307.1, U301.1 (EN)
unnamed: R308.1, U301.2 (RSET)
unnamed: JP302.1, R316.2, U302.5 (URx)
unnamed: JP303.1, R317.2, U302.6 (UTx)
unnamed: R313.2, U302.4 (~RESET)
POWER-+3V3: C306.1, K301.4, K301.5, LCD301.5 (VDD), P301.3, P302.3, R301.1, R303.1, R304.1, R311.1, R312.1, R313.1, R314.1, R316.1, R317.1, R318.1, R319.1, U302.1 (VDD), U302.11 (VUSB); also elsewhere on the board
POWER-+5V: C304.1, JP301.1, LCD301.A, U301.3 (VIN); also elsewhere on the board
POWER-GND: C301.2, C302.2, C304.2, C305.2, C306.2, C307.2, K301.6, K301.7, K301.8, K302.5, K302.6, LCD301.4 (VSS), P301.1, P302.1, R307.2, R308.2, S301.1, S301.2, S302.1, S302.2, S303.2 (C), S303.4, U301.5 (GND), U302.14 (VSS); also elsewhere on the board
ROTARY_A: K302.2, R310.1
ROTARY_B: K302.3, R315.2
ROTARY_S: K302.4, R309.1

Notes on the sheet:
AN1
GND
ROTARY A
ROTARY B
AN2
+3V3
CAT4002A (VL08) Ibckl: (125 * 0.6) / 2400 = ~30mA.
ROTARY S

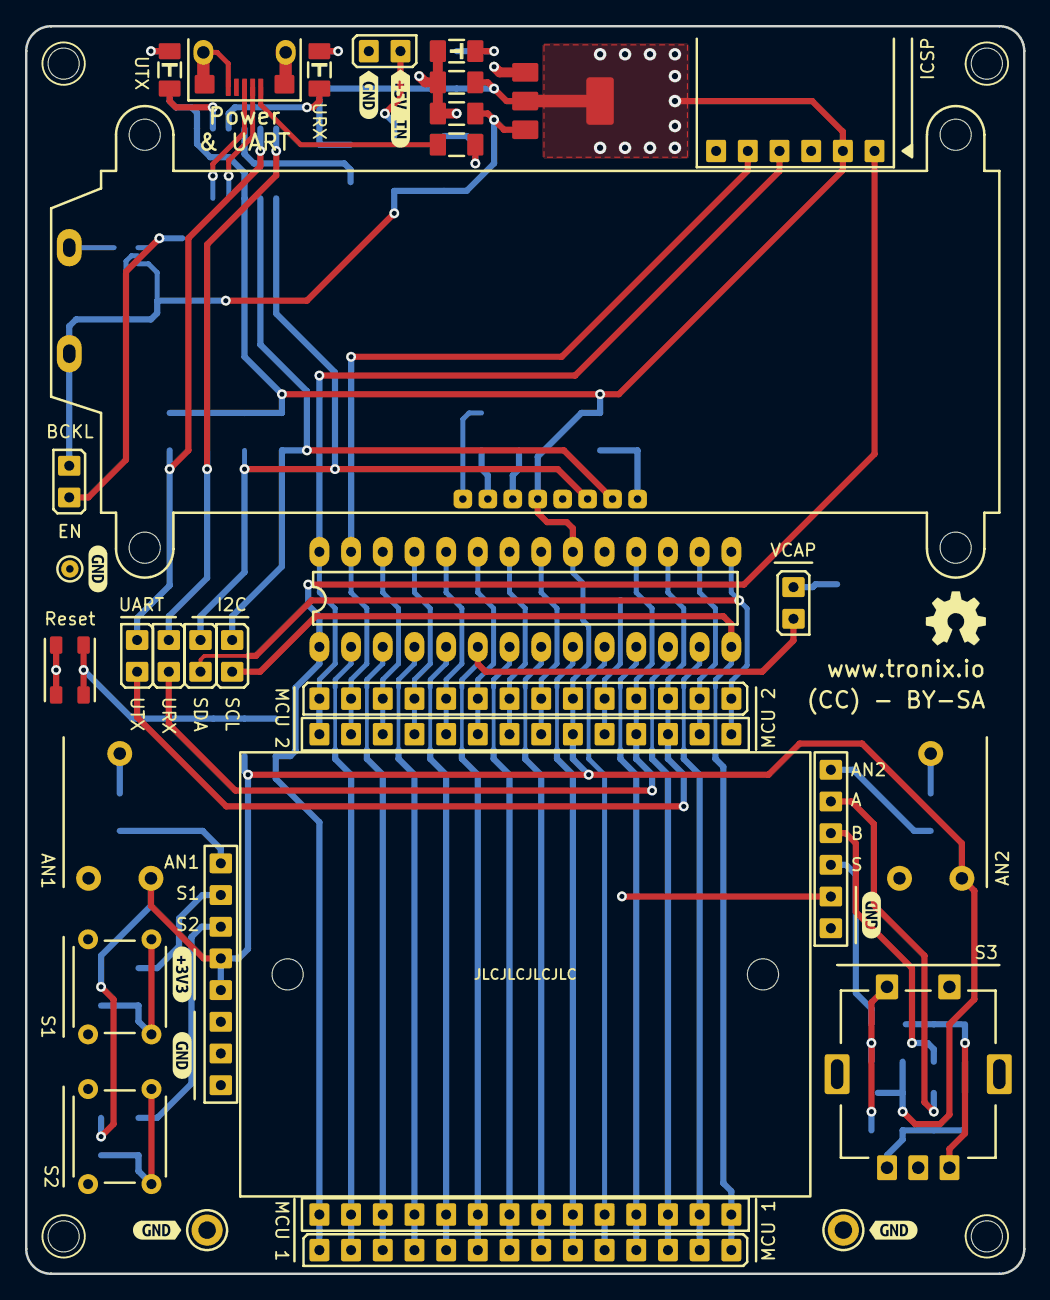
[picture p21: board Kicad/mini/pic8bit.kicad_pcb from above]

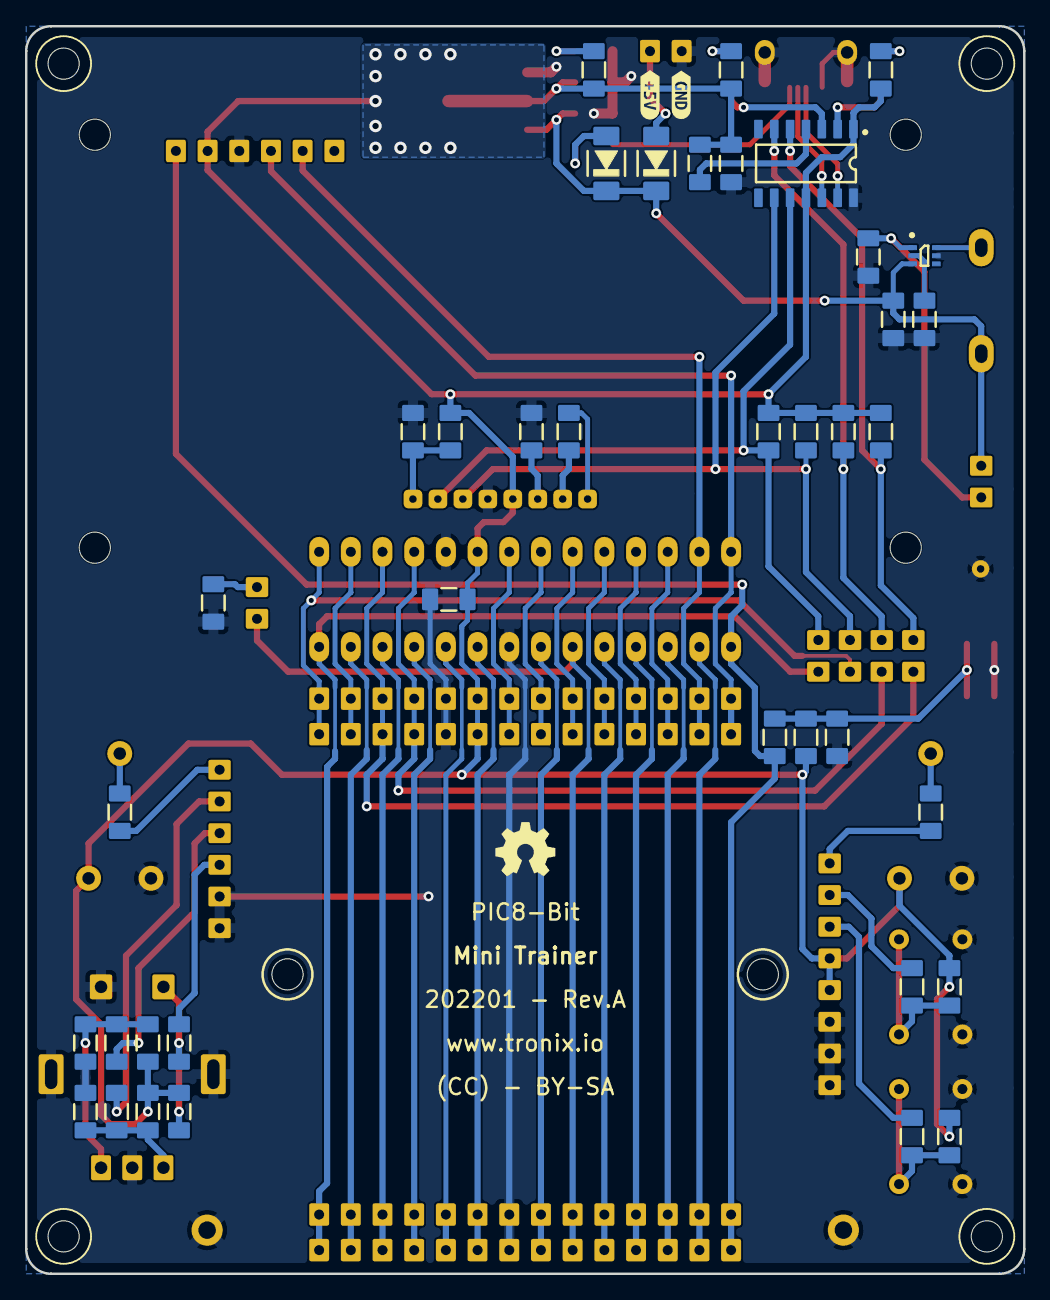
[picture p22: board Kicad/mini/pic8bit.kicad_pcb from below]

Board: 2 copper layers, 80.0 x 100.0 mm, 94 parts (41 on the bottom side), 66 nets.

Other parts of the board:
kibuzzard-65F5FBF2: G***; kibuzzard-65F5FBF2
kibuzzard-65F5FC1C: G***; kibuzzard-65F5FC1C
kibuzzard-65F5FC3B: G***; kibuzzard-65F5FC3B
kibuzzard-65F5FC4B: G***; kibuzzard-65F5FC4B
kibuzzard-65F5FC28: G***; kibuzzard-65F5FC28
kibuzzard-65F5FC57: G***; kibuzzard-65F5FC57
kibuzzard-65F5FC64: G***; kibuzzard-65F5FC64
kibuzzard-65F5FC73: G***; kibuzzard-65F5FC73
kibuzzard-65F5FC86: G***; kibuzzard-65F5FC86
kibuzzard-65F6B82D: G***; kibuzzard-65F6B82D

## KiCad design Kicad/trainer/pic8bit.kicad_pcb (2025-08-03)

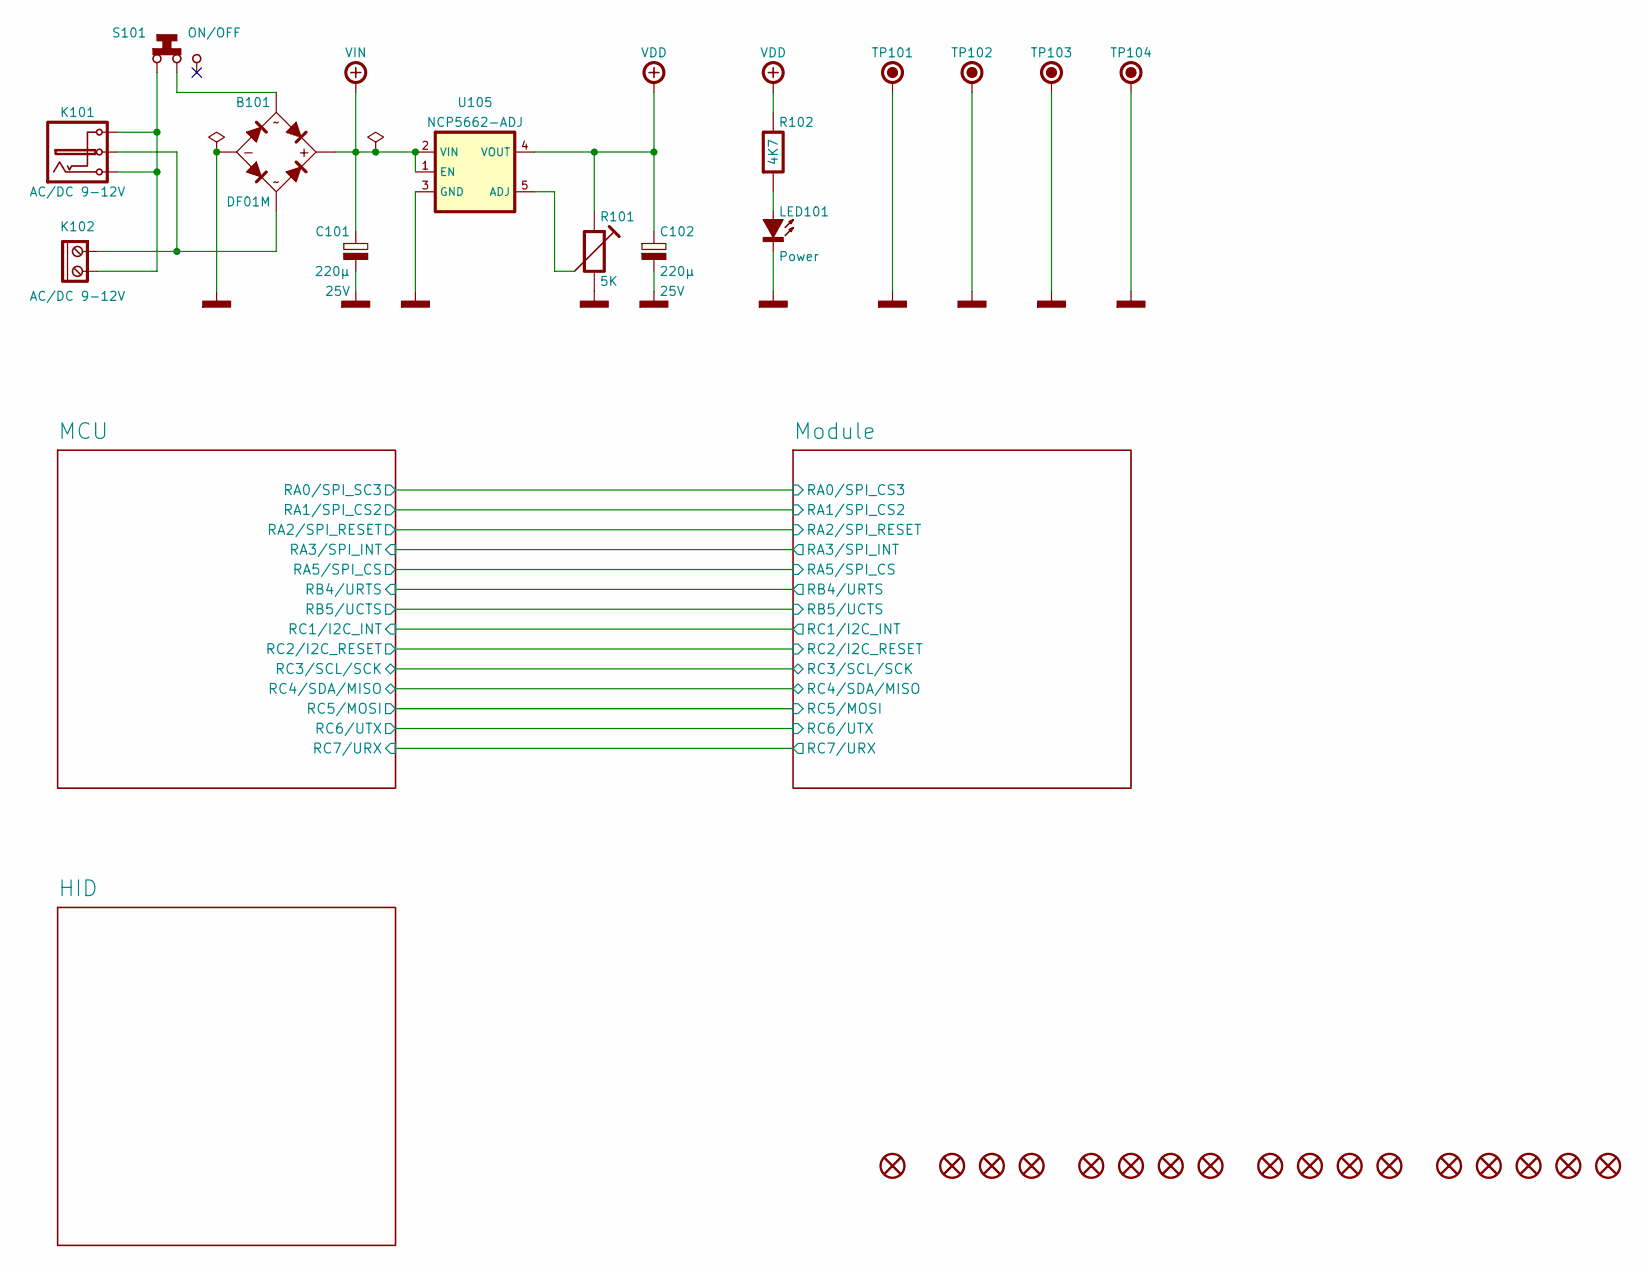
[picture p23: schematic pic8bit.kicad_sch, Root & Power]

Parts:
B101: DF01M; Mouser 512-DF01M
C101, C102: 220µ; CAPACITOR-ELECTROLYTIC-RADIAL-080-115-035; Voltage 25V; Tolerance 20%; Mouser 647-UVZ1E221MPD
H101, H102, H103, H104: HARWIN-JUMPER-0254-14MM-BLACK; HARWIN-M20-7680-7683; Mouser 855-M7682
JP101: HARWIN-JUMPER-0254-06MM-BLACK; HARWIN-M20-7580-7583; Mouser 855-M7582
JP102, JP103: HARWIN-JUMPER-0254-06MM-RED; HARWIN-M20-7580-7583; Mouser 855-M7581
K101: AC/DC 9-12V; SAMESKY-PJ-102AH; Mouser 490-PJ-102AH
K102: AC/DC 9-12V; SAMESKY-TB006-508-02BE; Mouser 490-TB006-508-02BE
K103: PE-450-4X6X-BLACK; PE-450-4X6X; Mouser 450-476
LED101: Power; LED-TH-ROUND-05MM; Mouser 604-WP7113ID
R101: 5K; TRIMMER-64W; Tolerance 10%; Mouser 594-64W502
R102: 4K7; RESISTOR-TH-1016; Tolerance 5%; Mouser 594-SFR2500004701JR5
S101: ON/OFF; CK-1101M2; Mouser 611-1101M2S3CQE2
TP101, TP102, TP103: GND; KEYSTONE-5006; Mouser 534-5006
TP104: GND; KEYSTONE-2000-3; Mouser 534-2000-3
U101, U102, U103, U104: KEYSTONE-24283; Mouser 534-24283
U105: NCP5662-ADJ; TO-263-5-TABPIN3; Mouser 863-NCP5662DSADJR4G
X101, X102, X103, X104, X105: 3M-SJ5376; Mouser 517-SJ5376

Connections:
unnamed: B101.3, K101.1, K102.1
unnamed: B101.4, S101.2
unnamed: K101.2, K101.3, K102.2, S101.1
unnamed: LED101.2 (A), R102.2
unnamed: R101.2, U105.5 (ADJ)
POWER-GND: B101.2, C101.2, C102.2, LED101.1 (C), R101.1, TP101.1, TP102.1, TP103.1, TP104.1, U105.3 (GND); also elsewhere on the board
POWER-VDD: C102.1, R101.3, R102.1, U105.4 (VOUT); also elsewhere on the board
POWER-VIN: B101.1, C101.1, U105.1 (EN), U105.2 (VIN); also elsewhere on the board

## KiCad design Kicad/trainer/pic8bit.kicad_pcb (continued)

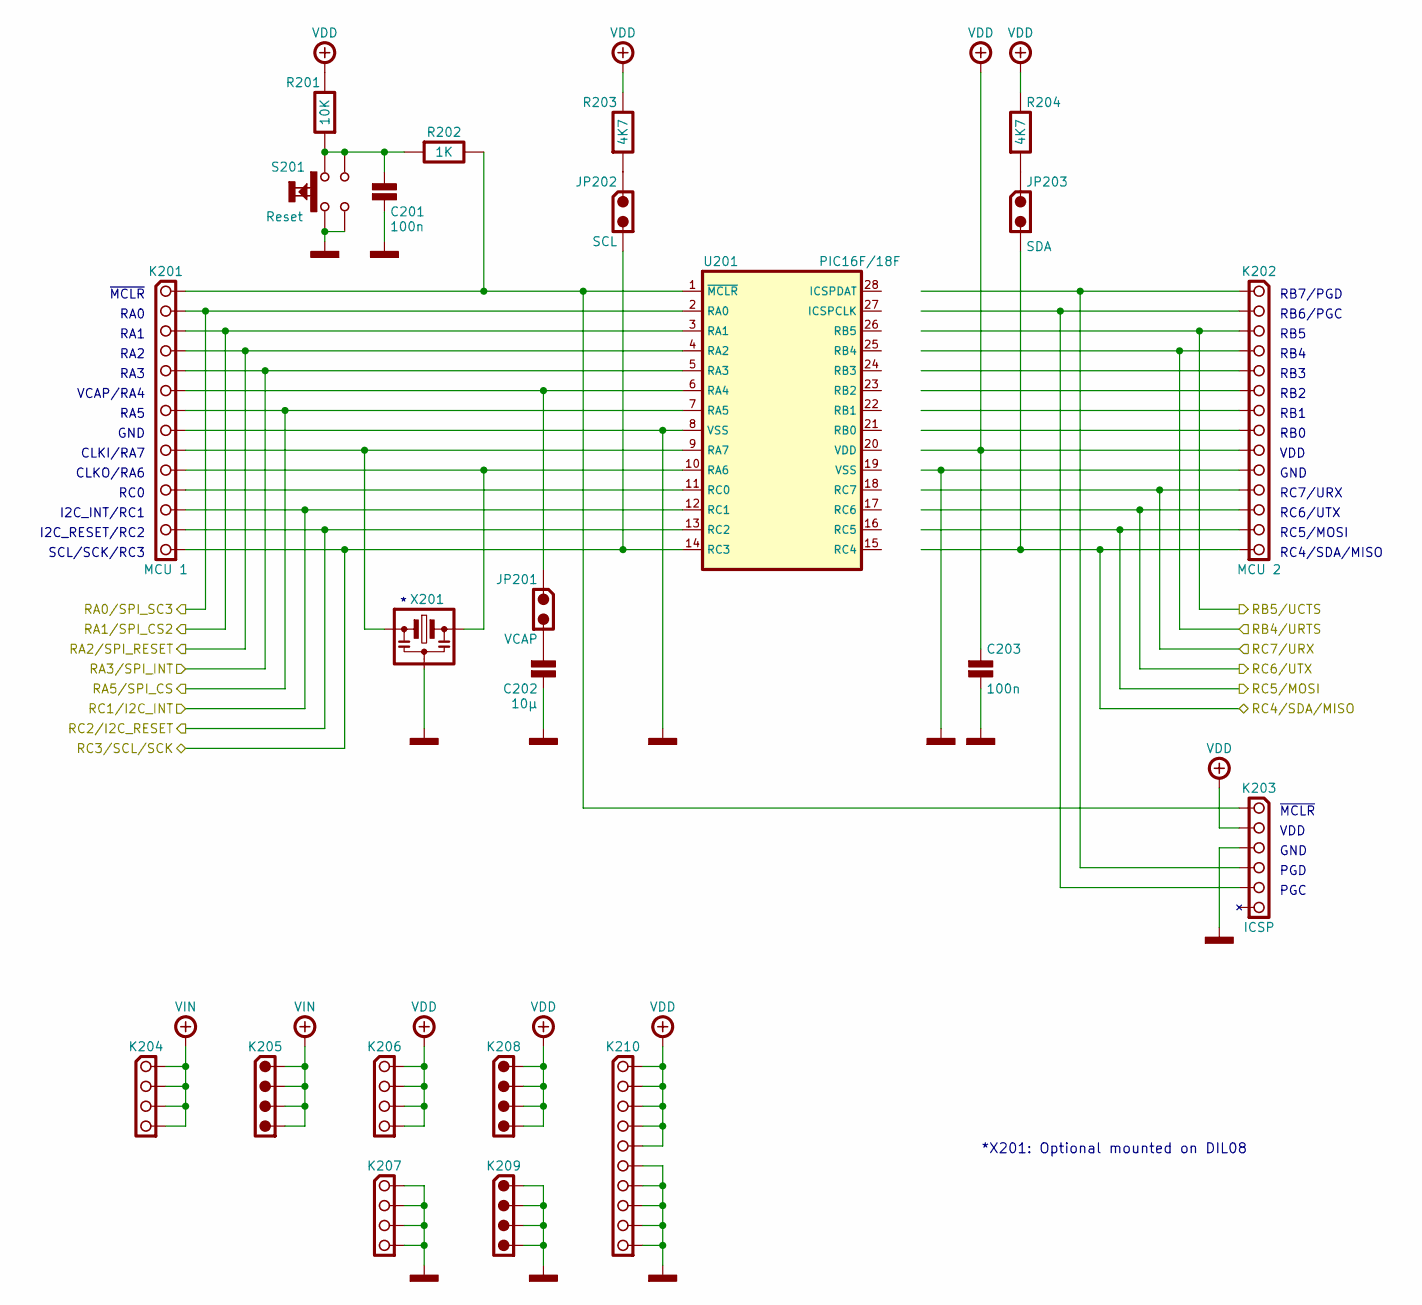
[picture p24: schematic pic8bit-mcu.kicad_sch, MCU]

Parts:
C201, C203: 100n; KEMET-C315; Tolerance 20%; Voltage 50V; Mouser 80-C315C104M5U
C202: 10µ; KEMET-C322; Tolerance 10%; Voltage 25V; Mouser 80-C322C106K3R
JP201: VCAP; HARWIN-M20-975024x; Mouser 855-M20-975024
JP202: SCL; HARWIN-M20-999024x; Mouser 855-M20-999024
JP203: SDA; HARWIN-M20-999024x; Mouser 855-M20-999024
K201: MCU 1; HARWIN-M20-782144x; Mouser 855-M20-782144
K202: MCU 2; HARWIN-M20-782144x; Mouser 855-M20-782144
K203: ICSP; SAMTEC-SSW-106-02-T-S-RA; Mouser 200-SSW10602TSRA
K204: VIN; HARWIN-M20-782044x; Mouser 855-M20-782044
K205: VIN; HARWIN-M20-999044x; Mouser 855-M20-999044
K206: VDD; HARWIN-M20-782044x; Mouser 855-M20-782044
K207: GND; HARWIN-M20-782044x; Mouser 855-M20-782044
K208: VDD; HARWIN-M20-999044x; Mouser 855-M20-999044
K209: GND; HARWIN-M20-999044x; Mouser 855-M20-999044
K210: VDD & GND; HARWIN-M20-782104x; Mouser 855-M20-782104
R201: 10K; RESISTOR-TH-1016; Tolerance 5%; Mouser 594-SFR2500001002JA5
R202: 1K; RESISTOR-TH-1016; Tolerance 5%; Mouser 594-SFR2500001001JR5
R203, R204: 4K7; RESISTOR-TH-1016; Tolerance 5%; Mouser 594-SFR2500004701JR5
S201: Reset; CK-KSA-TH; Mouser 611-KSA0M911LFT
U201: PIC16F/18F; DIP-28-W762; Mouser 579-PIC16F1778-I/SP
X201: XTAL-DIL08; DIP-08-W762-SOCKET; Mouser 575-144308

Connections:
/MCU/RA0/SPI_SC3: K201.2, U201.2 (RA0); also elsewhere on the board
/MCU/RA1/SPI_CS2: K201.3, U201.3 (RA1); also elsewhere on the board
/MCU/RA2/SPI_RESET: K201.4, U201.4 (RA2); also elsewhere on the board
/MCU/RA3/SPI_INT: K201.5, U201.5 (RA3); also elsewhere on the board
/MCU/RA5/SPI_CS: K201.7, U201.7 (RA5); also elsewhere on the board
/MCU/RB4/URTS: K202.4; also elsewhere on the board
/MCU/RB5/UCTS: K202.3; also elsewhere on the board
/MCU/RC1/I2C_INT: K201.12, U201.12 (RC1); also elsewhere on the board
/MCU/RC2/I2C_RESET: K201.13, U201.13 (RC2); also elsewhere on the board
/MCU/RC3/SCL/SCK: JP202.2, K201.14, U201.14 (RC3); also elsewhere on the board
/MCU/RC4/SDA/MISO: JP203.2, K202.14; also elsewhere on the board
/MCU/RC5/MOSI: K202.13; also elsewhere on the board
/MCU/RC6/UTX: K202.12; also elsewhere on the board
/MCU/RC7/URX: K202.11; also elsewhere on the board
unnamed: C201.1, R201.2, R202.2, S201.1, S201.2
unnamed: C202.1, JP201.2
unnamed: JP202.1, R203.2
unnamed: JP203.1, R204.2
unnamed: K201.1, K203.6 (~MCLR), R202.1, U201.1 (~MCLR)
unnamed: JP201.1, K201.6, U201.6 (RA4)
unnamed: K201.9, U201.9 (RA7), X201.3, X201.4
unnamed: K201.10, U201.10 (RA6), X201.5, X201.6
unnamed: K201.11, U201.11 (RC0)
unnamed: K202.1, K203.3 (PGD)
unnamed: K202.2, K203.2 (PGC)
POWER-GND: C201.2, C202.2, C203.2, K201.8, K202.10, K203.4 (GND), K207.1, K207.2, K207.3, K207.4, K209.1, K209.2, K209.3, K209.4, K210.6, K210.7, K210.8, K210.9, K210.10, S201.3, S201.4, U201.8 (VSS), X201.1, X201.2, X201.7, X201.8; also elsewhere on the board
POWER-VDD: C203.1, K202.9, K203.5 (VCC), K206.1, K206.2, K206.3, K206.4, K208.1, K208.2, K208.3, K208.4, K210.1, K210.2, K210.3, K210.4, K210.5, R201.1, R203.1, R204.1; also elsewhere on the board
POWER-VIN: K204.1, K204.2, K204.3, K204.4, K205.1, K205.2, K205.3, K205.4; also elsewhere on the board

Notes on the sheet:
RC6/UTX
VCAP/RA4
CLKI/RA7
VDD
PGC
RA3
RA0
RA2
RB6/PGC
RB5
*X201: Optional mounted on DIL08
RB7/PGD
~{MCLR}
GND
CLKO/RA6
PGD
RB4
RB2
RA1
RB3
RC5/MOSI
RA5
RB0
RC7/URX
RC4/SDA/MISO
I2C_INT/RC1
RC0
I2C_RESET/RC2
RB1
SCL/SCK/RC3

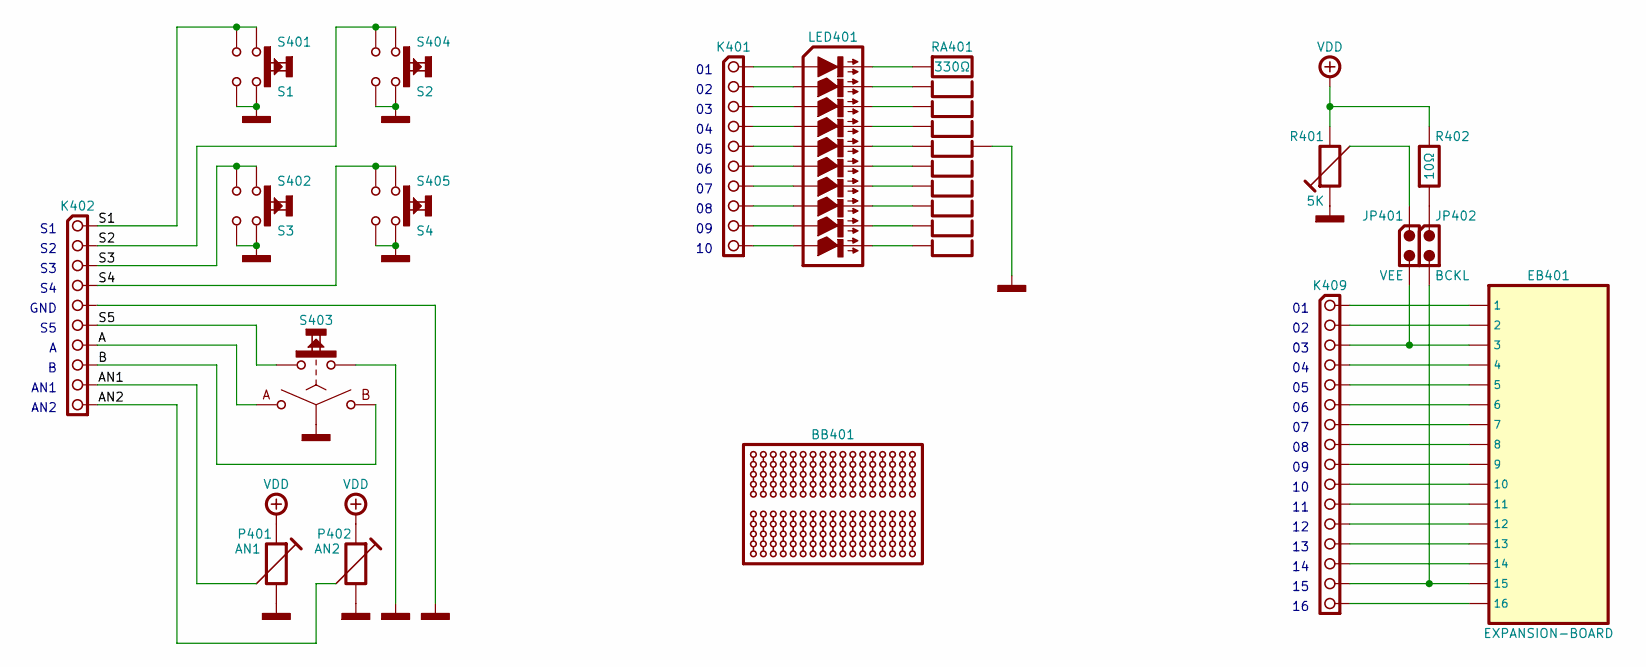
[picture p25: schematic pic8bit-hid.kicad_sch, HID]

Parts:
BB401: BREADBOARD-170; Mouser 854-BB170
EB401: EXPANSION-BOARD; TRONIXIO-EXPANSION-BOARD; Mouser 200-CES11601TS
JP401: VEE; HARWIN-M20-999024x; Mouser 855-M20-999024
JP402: BCKL; HARWIN-M20-999024x; Mouser 855-M20-999024
K401: LED ARRAY; HARWIN-M20-782104x; Mouser 855-M20-782104
K402: SWITCH, ENCODER & ANALOG; HARWIN-M20-782104x; Mouser 855-M20-782104
K409: EXPANSION BOARD; HARWIN-M20-782164x; Mouser 855-M20-782164
LED401: KINGBRIGHT-DC10EWA; KINGBRIGHT-DC; Mouser 604-DC-10EWA
P401: AN1; PIHER-PT10MV; Tolerance 20%; Mouser 531-PT10MV-10K
P402: AN2; PIHER-PT10MV; Tolerance 20%; Mouser 531-PT10MV-10K
R401: 5K; PIHER-PT10MV; Tolerance 20%; Mouser 531-PT10LV-5K
R402: 10Ω; RESISTOR-TH-1016; Tolerance 5%; Mouser 594-5043EM10R00J
RA401: 330Ω; BOURNS-4611X; Tolerance 2%; Mouser 652-4611X-1LF-330
S401: S1; CK-KSA-TH; Mouser 611-KSA0M911LFT
S402: S3; CK-KSA-TH; Mouser 611-KSA0M911LFT
S403: BOURNS-PEC12R-24DENTS; BOURNS-PEC12R-SWITCH; Mouser 652-PEC12R-4215F-S24
S404: S2; CK-KSA-TH; Mouser 611-KSA0M911LFT
S405: S4; CK-KSA-TH; Mouser 611-KSA0M911LFT

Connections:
/HID/A: K402.7, S403.1 (A)
/HID/AN1: K402.9, P401.2
/HID/AN2: K402.10, P402.2
/HID/B: K402.8, S403.3 (B)
/HID/S1: K402.1, S401.1, S401.2
/HID/S2: K402.2, S404.1, S404.2
/HID/S3: K402.3, S402.1, S402.2
/HID/S4: K402.4, S405.1, S405.2
/HID/S5: K402.6, S403.5
unnamed: JP401.1, R401.2
unnamed: JP402.1, R402.2
unnamed: K401.1, LED401.1 (A1)
unnamed: K401.2, LED401.2 (A2)
unnamed: K401.3, LED401.3 (A3)
unnamed: K401.4, LED401.4 (A4)
unnamed: K401.5, LED401.5 (A5)
unnamed: K401.6, LED401.6 (A6)
unnamed: K401.7, LED401.7 (A7)
unnamed: K401.8, LED401.8 (A8)
unnamed: K401.9, LED401.9 (A9)
unnamed: K401.10, LED401.10 (A10)
unnamed: EB401.1, K409.1
unnamed: EB401.2, K409.2
unnamed: EB401.3, JP401.2, K409.3
unnamed: EB401.4, K409.4
unnamed: EB401.5, K409.5
unnamed: EB401.6, K409.6
unnamed: EB401.7, K409.7
unnamed: EB401.8, K409.8
unnamed: EB401.9, K409.9
unnamed: EB401.10, K409.10
unnamed: EB401.11, K409.11
unnamed: EB401.12, K409.12
unnamed: EB401.13, K409.13
unnamed: EB401.14, K409.14
unnamed: EB401.15, JP402.2, K409.15
unnamed: EB401.16, K409.16
unnamed: LED401.20 (C1), RA401.2
unnamed: LED401.19 (C2), RA401.3
unnamed: LED401.18 (C3), RA401.4
unnamed: LED401.17 (C4), RA401.5
unnamed: LED401.16 (C5), RA401.6
unnamed: LED401.15 (C6), RA401.7
unnamed: LED401.14 (C7), RA401.8
unnamed: LED401.13 (C8), RA401.9
unnamed: LED401.12 (C9), RA401.10
unnamed: LED401.11 (C10), RA401.11
POWER-GND: K402.5, P401.1, P402.1, R401.3, RA401.1, S401.3, S401.4, S402.3, S402.4, S403.2 (C), S403.4, S404.3, S404.4, S405.3, S405.4; also elsewhere on the board
POWER-VDD: P401.3, P402.3, R401.1, R402.1; also elsewhere on the board

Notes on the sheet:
AN2
GND
AN1

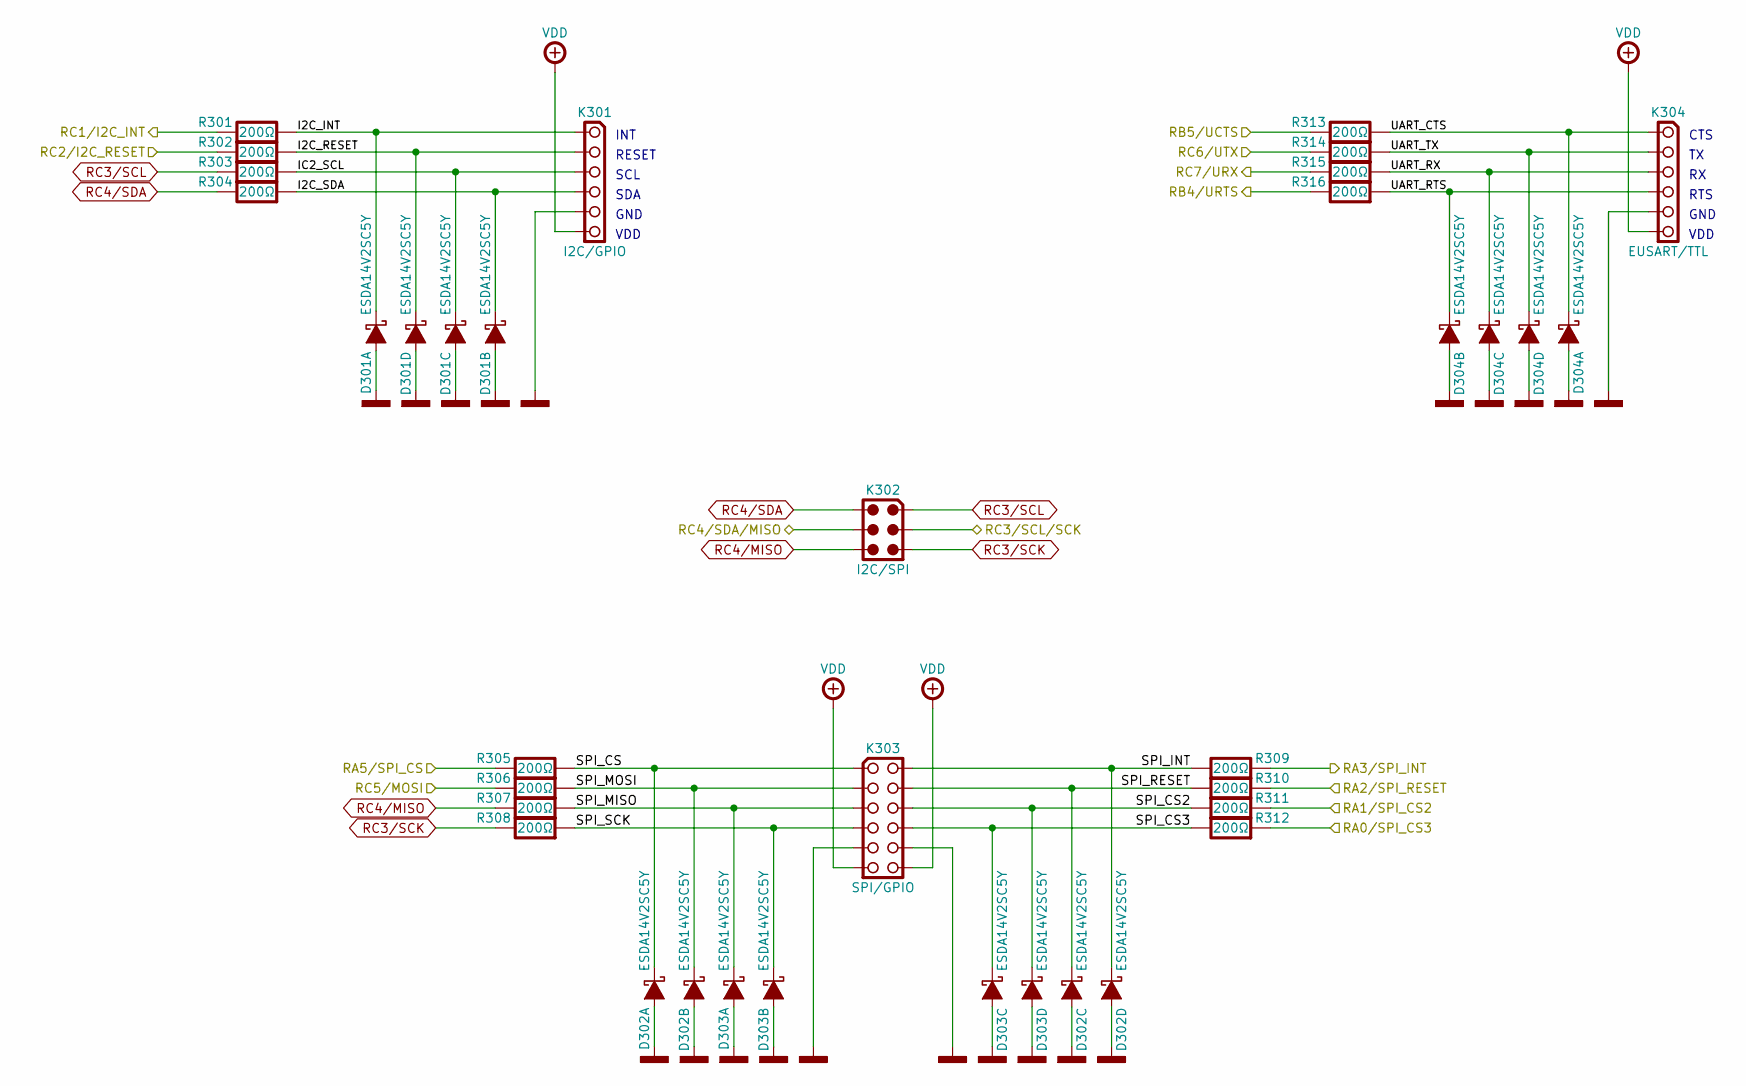
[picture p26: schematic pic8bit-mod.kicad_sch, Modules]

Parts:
D301, D302, D303, D304: ESDA14V2SC5Y; SOT-23-5; Mouser 511-ESDA14V2SC5Y
K301: I2C/GPIO; SAMTEC-SSW-106-02-T-S-RA; Mouser 200-SSW10603TSRA
K302: I2C/SPI; HARWIN-M20-974034x; Mouser 855-M20-974034
K303: SPI/GPIO; SAMTEC-SSW-106-02-T-D-RA; Mouser 200-SSW10602TDRA
K304: EUSART/TTL; SAMTEC-SSW-106-02-T-S-RA; Mouser 200-SSW10603TSRA
R301, R302, R303, R304, R305, R306, R307, R308, R309, R310, R311, R312, R313, R314, R315, R316: 200Ω; RESISTOR-SMD-1206; Tolerance 5%; Mouser 660-RK73B2BTTDD201J

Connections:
/MCU/RA0/SPI_SC3: R312.2; also elsewhere on the board
/MCU/RA1/SPI_CS2: R311.2; also elsewhere on the board
/MCU/RA2/SPI_RESET: R310.2; also elsewhere on the board
/MCU/RA3/SPI_INT: R309.2; also elsewhere on the board
/MCU/RA5/SPI_CS: R305.1; also elsewhere on the board
/MCU/RB4/URTS: R316.1; also elsewhere on the board
/MCU/RB5/UCTS: R313.1; also elsewhere on the board
/MCU/RC1/I2C_INT: R301.1; also elsewhere on the board
/MCU/RC2/I2C_RESET: R302.1; also elsewhere on the board
/MCU/RC3/SCL/SCK: K302.3; also elsewhere on the board
/MCU/RC4/SDA/MISO: K302.4; also elsewhere on the board
/MCU/RC5/MOSI: R306.1; also elsewhere on the board
/MCU/RC6/UTX: R314.1; also elsewhere on the board
/MCU/RC7/URX: R315.1; also elsewhere on the board
/Module/I2C_INT: D301.1 (C), K301.1, R301.2
/Module/I2C_RESET: D301.5 (C), K301.2, R302.2
/Module/I2C_SDA: D301.3 (C), K301.4, R304.2
/Module/IC2_SCL: D301.4 (C), K301.3, R303.2
/Module/SPI_CS: D302.1 (C), K303.1, R305.2
/Module/SPI_CS2: D303.5 (C), K303.6, R311.1
/Module/SPI_CS3: D303.4 (C), K303.8, R312.1
/Module/SPI_INT: D302.5 (C), K303.2, R309.1
/Module/SPI_MISO: D303.1 (C), K303.5, R307.2
/Module/SPI_MOSI: D302.3 (C), K303.3, R306.2
/Module/SPI_RESET: D302.4 (C), K303.4, R310.1
/Module/SPI_SCK: D303.3 (C), K303.7, R308.2
/Module/UART_CTS: D304.1 (C), K304.1, R313.2
/Module/UART_RTS: D304.3 (C), K304.4, R316.2
/Module/UART_RX: D304.4 (C), K304.3, R315.2
/Module/UART_TX: D304.5 (C), K304.2, R314.2
POWER-GND: D301.2 (A), D302.2 (A), D303.2 (A), D304.2 (A), K301.5, K303.9, K303.10, K304.5; also elsewhere on the board
POWER-VDD: K301.6, K303.11, K303.12, K304.6; also elsewhere on the board
RC3/SCK: K302.5, R308.1
RC3/SCL: K302.1, R303.1
RC4/MISO: K302.6, R307.1
RC4/SDA: K302.2, R304.1

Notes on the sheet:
INT
VDD
SCL
GND
SDA
CTS
RESET
RTS



Board: 2 copper layers, 160.0 x 100.0 mm, 117 parts (25 on the bottom side), 100 nets.

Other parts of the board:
kibuzzard-65F605A7: G***; kibuzzard-65F605A7
kibuzzard-65F605B3: G***; kibuzzard-65F605B3
kibuzzard-65F605BE: G***; kibuzzard-65F605BE
kibuzzard-65F605CA: G***; kibuzzard-65F605CA
kibuzzard-65F605D7: G***; kibuzzard-65F605D7
kibuzzard-65F605E6: G***; kibuzzard-65F605E6
kibuzzard-65F605F2: G***; kibuzzard-65F605F2
kibuzzard-65F6052C: G***; kibuzzard-65F6052C
kibuzzard-65F6056F: G***; kibuzzard-65F6056F
kibuzzard-65F6059C: G***; kibuzzard-65F6059C
kibuzzard-65F60515: G***; kibuzzard-65F60515
kibuzzard-65F60520: G***; kibuzzard-65F60520
kibuzzard-65F60537: G***; kibuzzard-65F60537
kibuzzard-65F60546: G***; kibuzzard-65F60546
kibuzzard-65F60553: G***; kibuzzard-65F60553
kibuzzard-65F60562: G***; kibuzzard-65F60562
kibuzzard-65F60578: G***; kibuzzard-65F60578
kibuzzard-65F60585: G***; kibuzzard-65F60585
kibuzzard-65F60590: G***; kibuzzard-65F60590
kibuzzard-65F60603: G***; kibuzzard-65F60603
kibuzzard-65F60610: G***; kibuzzard-65F60610

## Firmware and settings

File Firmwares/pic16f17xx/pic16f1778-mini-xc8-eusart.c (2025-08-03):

// Configuration Registers.
#pragma config FOSC = INTOSC, WDTE = OFF, PWRTE = OFF, MCLRE = ON, CP = OFF
#pragma config BOREN = OFF, CLKOUTEN = ON, IESO = OFF, FCMEN = OFF
#pragma config WRT = OFF, PPS1WAY = ON, ZCD = OFF, PLLEN = OFF
#pragma config STVREN = ON, BORV = LO, LPBOR = OFF, LVP = ON

#include <xc.h>
#include <stdint.h>
#define _XTAL_FREQ 8000000
// PIC16F1778 - Compile with XC8(v2.40).
// PIC16F1778 - @8MHz Internal Oscillator.

// DRAFT Do not use.

// Rotary encoder code from:
// https://www.mikrocontroller.net/articles/Drehgeber

// PIC8-Bit Mini Trainer.
// 2x ADC CHANNELS.
// 1x LCD NHD-C0220BiZ - ST7036.
// 1x EUSART RX/TX ASYNCHRONOUS.
// 1x ROTARY ENCODER with SWITCH.
// 2x SWITCHS.

// JUMPER.URX - Close.
// JUMPER.UTX - Close.
// JUMPER.SDA - Not Use.
// JUMPER.SCL - Not Use.
// JUMPER.VCAP - Open.
// JUMPER.BCKL - Open.

// Pinout.
// MCU.RA0 <- ANALOG.AN1.
// MCU.RA1 <- ANALOG.AN2.
// MCU.RA6 -> OSCILLOSCOPE.PROBE.A.
// MCU.RB0 <- SWITCH.S1.
// MCU.RB1 <- SWITCH.S2.
// MCU.RB2 <- ROTARY.A.
// MCU.RB3 <- ROTARY.B.
// MCU.RB4 <- ROTARY.S3.

// Definitions.
// ADC.
#define ADC_TRIGGER           5
// EUSART.
#define BAUDRATE              9600
#define BAUDRATE_GENERATOR    ((_XTAL_FREQ/BAUDRATE/4)-1)
// ASCII Characters.
#define ASCII_CR              0x0D
// Rotary Encoder.
#define ROTARY_PHASE_A        PORTBbits.RB2
#define ROTARY_PHASE_B        PORTBbits.RB3
#define ROTARY_SWITCH         PORTBbits.RB4
// Switchs.
#define SWITCH_S1             PORTBbits.RB0
#define SWITCH_S2             PORTBbits.RB1

// Function Prototypes.
uint8_t eusart_readCharacter(void);
void eusart_writeCharacter(uint8_t u8Data);
void eusart_writeString(const uint8_t * u8Data);
int8_t rotary_i8encoderFilter(void);
void u16toa(uint16_t u16Data, uint8_t * au8Buffer, uint8_t u8Base);

// Strings.
const uint8_t au8Tronix[] = "\r\n\r\nTronix I/O";
const uint8_t au8WWW[] = "\r\nhttps://www.tronix.io/\r\n";
const uint8_t au8Ready[] = "\r\nREADY> ";
const uint8_t au8Adc0[] = "\r\nADC CHANNEL 0> ";
const uint8_t au8Adc1[] = "\r\nADC CHANNEL 1> ";
const uint8_t au8Encoder[] = "\r\nROTARY ENCODER> ";
const uint8_t au8Encodersw[] = "\r\nROTARY ENCODER SWITCH> ";
const uint8_t au8Eusart[] = "\r\nEUSART ECHO> ";
const uint8_t au8Switch1[] = "\r\nSWITCH 1> ";
const uint8_t au8Switch2[] = "\r\nSWITCH 2> ";
const uint8_t au8Pressed[] = "PRESSED";
const uint8_t au8Released[] = "RELEASED";

const uint8_t au8encoder[16] = {0, 1, 255, 0, 255, 0, 0, 1, 1, 0, 0, 255, 0, 255, 1, 0};

// Global Variables.
int8_t i8encoderDelta;
uint16_t u16adcTimer;

// Interrupts Service Routines.
void __interrupt() ISR(void)
{
    if(INTCONbits.TMR0IF){
        static int8_t u8encoderLast = 0;
        u8encoderLast = (u8encoderLast<<2) & 0x0F;
        if(ROTARY_PHASE_A) u8encoderLast |= 0b01; // CW.
        if(ROTARY_PHASE_B) u8encoderLast |= 0b10; // CCW.
        i8encoderDelta += au8encoder[u8encoderLast];
        INTCONbits.TMR0IF = 0b0;
    }
    u16adcTimer++;
}

// Main.
void main(void)
{
    // MCU Initialization.
    // Internal Oscillator Settings.
    OSCTUNE = 0b00000000;
    OSCCON = 0x70;
    while(!OSCSTATbits.HFIOFR){};
    // Ports Settings.
    // PORT Data Register.
    PORTA = 0b00000000;
    PORTB = 0b00000000;
    PORTC = 0b00000000;
    // TRIS Data Direction.
    TRISA = 0b00000011;
    TRISB = 0b00011111;
    TRISC = 0b10000000;
    // WPU Disable.
    OPTION_REGbits.nWPUEN = 0b1;
    // LATCH Outputs.
    LATA = 0b00000000;
    LATB = 0b00000000;
    LATC = 0b00000000;
    // ANSEL Analog.
    ANSELA = 0b00000011;
    ANSELB = 0b00000000;
    ANSELC = 0b00000000;
    // WPU Weak Pull-up.
    WPUA = 0b00000000;
    WPUB = 0b00000000;
    WPUC = 0b00000000;
    // ODCON Open-drain.
    ODCONA = 0b00000000;
    ODCONB = 0b00000000;
    ODCONC = 0b00000000;
    // SRLCON Slew Rate.
    SLRCONA = 0b11111111;
    SLRCONB = 0b11111111;
    SLRCONC = 0b11111111;
    // INLVL Input Level.
    INLVLA  = 0b00000000;
    INLVLB  = 0b00000000;
    INLVLC  = 0b00000000;
    // HIDRVB High Drive.
    HIDRVB  = 0b00000000;
    // PPS Settings.
    // PPS Unlock Sequence.
    PPSLOCK = 0x55;
    PPSLOCK = 0xAA;
    PPSLOCKbits.PPSLOCKED = 0b0;
    // PPS Inputs.
    RXPPSbits.RXPPS = 0x17;    // RC7 - EUSART.URX.
    // PPS Outputs.
    RC6PPSbits.RC6PPS = 0x24;  // RC6 - EUSART.UTX.
    // PPS Lock Sequence.
    PPSLOCK = 0x55;
    PPSLOCK = 0xAA;
    PPSLOCKbits.PPSLOCKED = 0b1;

    // ADC Settings.
    ADRESL = 0;
    ADRESH = 0;
    ADCON0 = 0x00;
    ADCON1 = 0xD0;
    ADCON2 = 0x00;
    // ADC Enable.
    ADCON0bits.ADON = 0b1;

    // EUSART Settings.
    RC1REG = 0;
    TX1REG = 0;
    SP1BRG = BAUDRATE_GENERATOR;
    RC1STA = 0x10;
    TX1STA = 0x24;
    BAUD1CON = 0x08;
    // EUSART Enable.
    RC1STAbits.SPEN = 0b1;

    // Timer0 Settings.
    // ~500Hz @8MHz.
    OPTION_REGbits.PS = 0b010;
    OPTION_REGbits.PSA = 0b0;
    OPTION_REGbits.TMR0CS = 0b0;
    // Timer0 Interrupts Enable.
    INTCONbits.TMR0IE = 0b1;
    INTCONbits.TMR0IF = 0b0;

    // Display Strings.
    eusart_writeString(au8Tronix);
    eusart_writeString(au8WWW);
    eusart_writeString(au8Ready);

    // Interrupts Enable.
    INTCONbits.GIE = 0b1;

    uint8_t u8Rx;
    uint8_t au8Buffer[6];
    uint16_t u16ADCRead, u16ADC0Last, u16ADC1Last;
    uint8_t u8encoderSwitchPressed;
    uint8_t u8encoderRead, u8encoderLast;
    uint8_t u8switchS1Pressed, u8switchS2Pressed;
    while(1){
        // ADC Read every ~1s.
        if(u16adcTimer>1000){
            ADCON0bits.CHS = 0b00000;
            __delay_us(5);
            ADCON0bits.GO = 0b1;
            while(ADCON0bits.GO){};
            u16ADCRead = (uint16_t)(ADRESH<<8) + ADRESL;
            if(u16ADC0Last < (u16ADCRead - ADC_TRIGGER) || u16ADC0Last > (u16ADCRead + ADC_TRIGGER)){
                u16toa(u16ADCRead, au8Buffer, 10);
                eusart_writeString(au8Adc0);
                eusart_writeString(au8Buffer);
            }
            u16ADC0Last = u16ADCRead;
            ADCON0bits.CHS = 0b00001;
            __delay_us(5);
            ADCON0bits.GO = 0b1;
            while(ADCON0bits.GO){};
            u16ADCRead = (uint16_t)(ADRESH<<8) + ADRESL;
            if(u16ADC1Last < (u16ADCRead - ADC_TRIGGER) || u16ADC1Last > (u16ADCRead + ADC_TRIGGER)){
                u16toa(u16ADCRead, au8Buffer, 10);
                eusart_writeString(au8Adc1);
                eusart_writeString(au8Buffer);
            }
            u16ADC1Last = u16ADCRead;
            u16adcTimer = 0;
        }

        // EUSART.
        if(PIR1bits.RCIF){
            u8Rx = eusart_readCharacter();
            eusart_writeString(au8Eusart);
            eusart_writeCharacter(u8Rx);
            if(u8Rx == ASCII_CR)
                eusart_writeString(au8Ready);
        }

        // ROTARY ENCODER.
        if(!ROTARY_SWITCH){
            __delay_ms(100);
            u8encoderSwitchPressed = 1;
            eusart_writeString(au8Encodersw);
            eusart_writeString(au8Pressed);
            while(!ROTARY_SWITCH){};
        }else if(ROTARY_SWITCH){
            if(u8encoderSwitchPressed){
                u8encoderSwitchPressed = 0;
                eusart_writeString(au8Encodersw);
                eusart_writeString(au8Released);
                u8encoderRead = 0;
            }
        }

        u8encoderRead += rotary_i8encoderFilter();
        if(u8encoderLast != u8encoderRead){
            u16toa(u8encoderRead, au8Buffer, 10);
            eusart_writeString(au8Encoder);
            eusart_writeString(au8Buffer);
            u8encoderLast = u8encoderRead;
        }

        // SWITCHS.
        if(!SWITCH_S1){
            __delay_ms(100);
            u8switchS1Pressed = 1;
            eusart_writeString(au8Switch1);
            eusart_writeString(au8Pressed);
        }else if(SWITCH_S1){
            if(u8switchS1Pressed){
                eusart_writeString(au8Switch1);
                eusart_writeString(au8Released);
                u8switchS1Pressed = 0;
            }
        }
        if(!SWITCH_S2){
            __delay_ms(100);
            u8switchS2Pressed = 1;
            eusart_writeString(au8Switch2);
            eusart_writeString(au8Pressed);
        }else if(SWITCH_S2){
            if(u8switchS2Pressed){
                eusart_writeString(au8Switch2);
                eusart_writeString(au8Released);
                u8switchS2Pressed = 0;
            }
        }
    }
}

// Functions.
uint8_t eusart_readCharacter(void)
{
    if(RC1STAbits.OERR){
        RC1STAbits.CREN = 0b0;
        RC1STAbits.CREN = 0b1;
    }

    while(!PIR1bits.RCIF){};
    return(RC1REG);
}

void eusart_writeCharacter(uint8_t u8Data)
{
    while(!PIR1bits.TXIF){};
    TX1REG = u8Data;
}

void eusart_writeString(const uint8_t * u8Data)
{
    while(*u8Data != '\0')
        eusart_writeCharacter(*u8Data++);
}

int8_t rotary_i8encoderFilter(void)
{
    int8_t i8encoderFilter;

    INTCONbits.TMR0IE = 0b0;
    i8encoderFilter = i8encoderDelta;
    i8encoderDelta = i8encoderFilter & 3;
    INTCONbits.TMR0IE = 0b1;

    return(i8encoderFilter>>2);
}

void u16toa(uint16_t u16Data, uint8_t * au8Buffer, uint8_t u8Base)
{
    uint8_t u8Buffer;
    uint16_t data = u16Data;

    while(data != '\0'){
        data /= u8Base;
        au8Buffer++;
    }
    *au8Buffer-- = 0;

    while(u16Data != '\0'){
        u8Buffer = (uint8_t)(u16Data % u8Base);
        u16Data /= u8Base;
        if(u8Buffer >= 10)
            u8Buffer += 'A' - '0' - 10;
        u8Buffer += '0';
        *au8Buffer-- = u8Buffer;
    }
}

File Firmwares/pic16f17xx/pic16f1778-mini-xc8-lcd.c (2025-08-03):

// Configuration Registers.
#pragma config FOSC = INTOSC, WDTE = OFF, PWRTE = OFF, MCLRE = ON, CP = OFF
#pragma config BOREN = OFF, CLKOUTEN = ON, IESO = OFF, FCMEN = OFF
#pragma config WRT = OFF, PPS1WAY = ON, ZCD = OFF, PLLEN = OFF
#pragma config STVREN = ON, BORV = LO, LPBOR = OFF, LVP = ON

#include <xc.h>
#include <stdint.h>
#define _XTAL_FREQ 8000000
// PIC16F1778 - Compile with XC8(v2.40).
// PIC16F1778 - @8MHz Internal Oscillator.
    
// DRAFT Do not use.

// Rotary encoder code from:
// https://www.mikrocontroller.net/articles/Drehgeber

// PIC8-Bit Mini Trainer.
// 2x ADC CHANNELS.
// 1x LCD NHD-C0220BiZ - ST7036.
// 1x EUSART RX/TX ASYNCHRONOUS.
// 1x ROTARY ENCODER with SWITCH.
// 2x SWITCHS.

// JUMPER.URX - Not Use.
// JUMPER.UTX - Not Use.
// JUMPER.SDA - Close.
// JUMPER.SCL - Close.
// JUMPER.VCAP - Open.
// JUMPER.BCKL - Open.

// Pinout.
// MCU.RA0 <- ANALOG.AN1.
// MCU.RA1 <- ANALOG.AN2.
// MCU.RA6 -> OSCILLOSCOPE.PROBE.A.
// MCU.RB0 <- SWITCH.S1.
// MCU.RB1 <- SWITCH.S2.
// MCU.RB2 <- ROTARY.A.
// MCU.RB3 <- ROTARY.B.
// MCU.RB4 <- ROTARY.S3.
// MCU.RB5 -> LCD.BACKLIGHT.EN.

// Definitions.
// I2C.
#define I2C_READ                                           0b1
#define I2C_WRITE                                          0b0
#define I2C_FSCL_HZ                                        200000
#define I2C_BAUDRATE                                       ((_XTAL_FREQ/(4*I2C_FSCL_HZ))-1)
// ADC.
#define ADC_TRIGGER                                        5
// CAT4002A.
#define CAT4002_DELAY_DIM_MS                               5
#define CAT4002_DELAY_LED_US                               10
// ST7036 I2C Address.
#define ST7036_I2C_ADDRESS_78                              0x78
#define ST7036_I2C_CONTROL_CONTINUOUS_COMMAND              0x00
#define ST7036_I2C_CONTROL_CONTINUOUS_DATA                 0x40
#define ST7036_I2C_CONTROL_NO_CONTINUOUS_COMMAND           0x80
#define ST7036_I2C_CONTROL_NO_CONTINUOUS_DATA              0xC0
// ST7036 Instruction Table IS2=0, IS1=0.
#define ST7036_CLEAR_DISPLAY                               0x01
#define ST7036_RETURN_HOME                                 0x02
#define ST7036_ENTRY_MODE_SET_DDRAM_DECREMENT_NOSHIFT      0x04
#define ST7036_ENTRY_MODE_SET_DDRAM_DECREMENT_SHIFT_RIGHT  0x05
#define ST7036_ENTRY_MODE_SET_DDRAM_INCREMENT_NOSHIFT      0x06
#define ST7036_ENTRY_MODE_SET_DDRAM_INCREMENT_SHIFT_LEFT   0x07
#define ST7036_DISPLAY_OFF                                 0x08
#define ST7036_DISPLAY_ON_CURSOR_OFF                       0x0C
#define ST7036_DISPLAY_ON_CURSOR_ON_NOBLINK                0x0E
#define ST7036_DISPLAY_ON_CURSOR_ON_BLINK                  0x0F
#define ST7036_DISPLAY_CURSOR_SHIFT_LEFT                   0x10
#define ST7036_DISPLAY_CURSOR_SHIFT_RIGHT                  0x14
#define ST7036_DISPLAY_DISPLAY_SHIFT_LEFT                  0x18
#define ST7036_DISPLAY_DISPLAY_SHIFT_RIGH                  0x1C
#define ST7036_FUNCTION_SET_4_BIT_ONE_LINE_FONT5x8         0x20
#define ST7036_FUNCTION_SET_4_BIT_ONE_LINE_FONT5x8_IS1     0x21
#define ST7036_FUNCTION_SET_4_BIT_ONE_LINE_FONT5x8_IS2     0x22
#define ST7036_FUNCTION_SET_4_BIT_TWO_LINE_FONT5x8         0x28
#define ST7036_FUNCTION_SET_4_BIT_ONE_LINE_DHFONT5x8       0x24
#define ST7036_FUNCTION_SET_4_BIT_TWO_LINE_DHFONT5x8       0x2C
#define ST7036_FUNCTION_SET_8_BIT_ONE_LINE_FONT5x8         0x30
#define ST7036_FUNCTION_SET_8_BIT_ONE_LINE_FONT5x8_IS1     0x31
#define ST7036_FUNCTION_SET_8_BIT_ONE_LINE_FONT5x8_IS2     0x32
#define ST7036_FUNCTION_SET_8_BIT_ONE_LINE_DHFONT5x8       0x34
#define ST7036_FUNCTION_SET_8_BIT_TWO_LINE_FONT5x8         0x38
#define ST7036_FUNCTION_SET_8_BIT_TWO_LINE_DHFONT5x8       0x3C
#define ST7036_SET_ICON_RAM_ADDRESS                        0X40
#define ST7036_SET_CGRAM_ADDRESS                           0x40
#define ST7036_DDRAM_ADDRESS_FIRST_LINE                    0x80
#define ST7036_DDRAM_ADDRESS_SECOND_LINE                   0xC0
// ST7036 Instruction Table IS2=0, IS1=1.
#define ST7036_BIAS_SET_1_5                                0x14
#define ST7036_BIAS_SET_1_5_3_LINE                         0x15
#define ST7036_BIAS_SET_1_4                                0x1C
#define ST7036_BIAS_SET_1_4_3_LINE                         0x1D
#define ST7036_POWER_ICON_OFF_BOOST_OFF_NO_CONTRAST        0x50
#define ST7036_POWER_ICON_ON_BOOST_OFF_NO_CONTRAST         0x58
#define ST7036_POWER_ICON_OFF_BOOST_ON_CONTRAST_MSB_0      0x54
#define ST7036_POWER_ICON_OFF_BOOST_ON_CONTRAST_MSB_1      0x55
#define ST7036_POWER_ICON_OFF_BOOST_ON_CONTRAST_MSB_2      0x56
#define ST7036_POWER_ICON_OFF_BOOST_ON_CONTRAST_MSB_3      0x57
#define ST7036_POWER_ICON_ON_BOOST_ON_CONTRAST_MSB_0       0x5C
#define ST7036_POWER_ICON_ON_BOOST_ON_CONTRAST_MSB_1       0x5D
#define ST7036_POWER_ICON_ON_BOOST_ON_CONTRAST_MSB_2       0x5E
#define ST7036_POWER_ICON_ON_BOOST_ON_CONTRAST_MSB_3       0x5F
#define ST7036_FOLLOWER_CONTROL_OFF                        0x60
#define ST7036_FOLLOWER_CONTROL_ON_RAB_0                   0x68
#define ST7036_FOLLOWER_CONTROL_ON_RAB_1                   0x69
#define ST7036_FOLLOWER_CONTROL_ON_RAB_2                   0x6A
#define ST7036_FOLLOWER_CONTROL_ON_RAB_3                   0x6B
#define ST7036_FOLLOWER_CONTROL_ON_RAB_4                   0x6C
#define ST7036_FOLLOWER_CONTROL_ON_RAB_5                   0x6D
#define ST7036_FOLLOWER_CONTROL_ON_RAB_6                   0x6E
#define ST7036_FOLLOWER_CONTROL_ON_RAB_7                   0x6F
#define ST7036_CONTRAST_LSB_0                              0x70
#define ST7036_CONTRAST_LSB_1                              0x71
#define ST7036_CONTRAST_LSB_2                              0x72
#define ST7036_CONTRAST_LSB_3                              0x73
#define ST7036_CONTRAST_LSB_4                              0x74
#define ST7036_CONTRAST_LSB_5                              0x75
#define ST7036_CONTRAST_LSB_6                              0x76
#define ST7036_CONTRAST_LSB_7                              0x77
#define ST7036_CONTRAST_LSB_8                              0x78
#define ST7036_CONTRAST_LSB_9                              0x79
#define ST7036_CONTRAST_LSB_10                             0x7A
#define ST7036_CONTRAST_LSB_11                             0x7B
#define ST7036_CONTRAST_LSB_12                             0x7C
#define ST7036_CONTRAST_LSB_13                             0x7D
#define ST7036_CONTRAST_LSB_14                             0x7E
#define ST7036_CONTRAST_LSB_15                             0x7F
// ST7036 Instruction Table IS2=1, IS1=0.
#define ST7036_DOUBLE_HEIGHT_FONT_COM9_COM24               0x10
#define ST7036_DOUBLE_HEIGHT_FONT_COM1_COM16               0x11
// ST7036 Delays.
#define ST7036_CLEAR_DISPLAY_DELAY_MS                      2
#define ST7036_INITIALIZATION_DELAY_MS                     50
// NHD-C0220BiZ Configuration.
#define C0220BiZ_CONFIGURATION_I2C_ADDRESS                 ST7036_I2C_ADDRESS_78
#define C0220BiZ_CONFIGURATION_FIRST_LINE                  ST7036_DDRAM_ADDRESS_FIRST_LINE
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
